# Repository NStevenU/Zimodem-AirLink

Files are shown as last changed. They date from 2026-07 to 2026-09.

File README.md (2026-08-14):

<p align="center">
  AirLink Serial 56K Logo
</p>

<p align="center">
  <strong>ESP32-C3 기반 IBM PC Serial - WiFi 모뎀 에뮬레이터 (한국어 지원!)</strong><br>
  <em>Based on <a href="https://github.com/bozimmerman/Zimodem">Zimodem 4.0</a> by Bo Zimmerman</em>
</p>

---

## 📌 Overview
**AirLink 56K**는 Zimodem 펌웨어를 기반으로 최적화와 수정, 개선을 거친 WiFi 모뎀 펌웨어입니다. 레트로 IBM PC 환경에 완벽하게 호환되도록 설계되었으며, **ESP32-C3** 칩셋의 성능을 활용하여 실제 모뎀의 감성적인 사운드와 현대적인 편의성(VT100 메뉴, 한글 지원 등)을 동시에 제공합니다.
(AirLink는 실제로 존재하는 브랜드가 아니며 그냥 어울리도록 만든 것입니다. 누구나 따라 사용하실 수 있습니다.)

> 🇰🇷 **Note for International Users:** 
> This firmware is highly optimized for the Korean environment. While English is fully supported, please note that Korean is set as the default language.

**중요한 점**으로 이 펌웨어는 단순히 개인적인 용도로 프로젝트를 만들어 만든 것이기 때문에 최종 완성본이 아니며, 각종 문제 또는 미숙한 부분, 버그등이 발생할 수 있습니다.
또한 수정되거나 추가된 기능 대비 설명이 부족한 부분도 있습니다.

## ✨ Key Modifications & Features
* **최신 개발 환경 대응**: 최신 Arduino IDE, ESP-IDF v5.0 이상 대응
* **AirLink 브랜드 적용**: ESP32-C3, MAX3232, Buzzer를 결합한 하드웨어에 사용할 브랜드 적용(그래야지 진짜 물건같고 있어보이잖아요?ㅎㅎ)
* **IBM PC 전용 최적화**: 범용 레트로 PC 지원 코드를 덜어내고, ESP32-C3에 맞지 않는 불필요한 명령어 비활성화
* **모뎀 사운드 에뮬레이션!!!**: 
  * 전화 벨소리(Ringing), DTMF 다이얼 톤, V.90 모뎀 접속음을 추가 및 유기적 연동
  * 실제 문자열 접속 주소 입력 시, 사운드 출력을 위해 DTMF 음으로 자동 대체하여 레트로 감성 극대화
* **VT100 대화형 설정 메뉴**: 터미널에서 직관적으로 모뎀을 세팅할 수 있는 `AT+CONFIG` 메뉴 전면 개편
* **완벽한 한국어(EUC-KR) 지원**: 설정 메뉴 및 출력 메시지에서 영어/한국어 선택 기능 추가
* **사용자 편의성 강화**: 자체 도움말 기능(`AT+HELP`) 및 기타 마이너 편의 기능 탑재
* **한국 맞춤 최적화**: 인터넷 연결 기능인 SLIP, PPP기능의 가상번호를 PC통신 느낌이 나도록 014XY로 바꾸어, 01480, 01481로 수정
* **완벽한 Windows 9X PPP 호환성**: 
  * 기존 펌웨어에 없던 PAP(Password Authentication Protocol) 인증 로직을 자체적으로 완전 신규 구현하여 "사용자 이름 및 암호 확인 중" 화면에서 멈추는 고질적 문제 해결
  * IPCP(IP Control Protocol) 교섭 과정에서 모뎀과 윈도우 간의 IP 할당 충돌(Conflict) 방지 알고리즘 적용 및 NAK/REJ 핸들링 추가
* **레트로 모뎀 속도 완벽 에뮬레이션 (QoS 대역폭 제한)**:
  * Token Bucket 알고리즘을 도입하여 56K, 33.6K, 28.8K, 14.4K, 9.6K, 2.4K 등 과거 전화선 모뎀 특유의 병목 현상과 느린 전송 속도를 완벽하게 재현 (PPP, SLIP, 일반 Stream 모드 전체에 일괄 적용, 물론 무제한(0)으로 설정하여 최고속도로 사용가능)
* **상태 표시(Status) LED 기능 활성화**:
  * ESP32-C3 하드웨어 핀 맵핑을 전면 재정비하고, 직관적인 상태 파악을 위한 3개의 LED(PWR 전원, WIFI 연결 상태, RX/TX 데이터 송수신) 깜빡임 기능 추가
* **USB 비상 디버그 콘솔 (Emergency Backdoor)**:
  * 본선 시리얼 터미널이 먹통이 되었을 때 칩의 USB 포트(115200bps)로 직접 연결하여 하드웨어 강제 재부팅(`RESET`), 속도 강제 복구(`BAUD=`), 공장 초기화(`FACTORY`) 등을 수행할 수 있는 비상 커맨드 시스템 구축

## 🔌 Hardware Configuration (AirLink ESP32-C3 Pinout)

기존 범용 ESP32에 맞춰져 있던 핀 배열을 AirLink 하드웨어(ESP32-C3)에 최적화하여 새롭게 맵핑했습니다.<br/>모뎀 터미널 프로그램 설정 시 아래의 기본값을 참고하세요.

### 1. 시리얼 통신 기본 설정 (Default Serial Settings)
* **기본 모뎀 통신 포트 (UART0)**
  * **기본 속도 (Baud Rate)**: `115200 bps` 
  * **통신 포맷**: `8-N-1` (8 Data bits, No Parity, 1 Stop bit)
  * **흐름 제어 (Flow Control)**: `소프트웨어 방식 (XON/XOFF)`이 기본으로 활성화되어 있으며, 필요시 `AT&K` 명령어, 또는 `AT+CONFIG` 메뉴에서 하드웨어(RTS/CTS) 제어로 변경할 수 있습니다. **추천하는 것은 이후 아래에 설명된 `하드웨어 방식 (CTS/RTS)`을 사용하는 것입니다.**
* **USB 비상 디버그 포트 (USB CDC)**
  * 기기를 컴퓨터에 직접 USB로 연결하면 **비상 콘솔(115200 bps)** 에 접속할 수 있습니다. 메인 통신이 설정 오류로 먹통이 될 경우, 이 포트를 통해 `BAUD=`, `FACTORY`, `RESET` 등의 복구 명령을 내릴 수 있습니다.

### 2. ESP32-C3 핀 맵핑 (Pin Map)
사용자 커스텀 보드를 제작하거나 모듈을 직접 배선할 경우 아래의 핀 배열을 준수해야 합니다.

| 기능 (Function) | 설명 (Description) | GPIO 번호 (ESP32-C3) |
|:---:|---|:---:|
| **TXD** | UART Transmit Data (PC 수신) | `기본 UART0 TX (GPIO 21)` |
| **RXD** | UART Receive Data (PC 송신) | `기본 UART0 RX (GPIO 20)` |
| **DCD** | Data Carrier Detect | `GPIO 8` |
| **DTR** | Data Terminal Ready | `GPIO 5` |
| **DSR** | Data Set Ready | `GPIO 4` |
| **RTS** | Request To Send | `GPIO 2` |
| **CTS** | Clear To Send | `GPIO 3` |
| **RI** | Ring Indicator | `GPIO 1` |
| **SND** | 오디오 출력 (Buzzer/Speaker) | `GPIO 6` |
| **WIFI LED** | WiFi 연결 상태 표시 (Active LOW) | `GPIO 10` |
| **RXTX LED** | 데이터 송수신 표시 (Active LOW) | `GPIO 9` |
| **PWR LED** | 전원 표시 | 하드웨어 직결 권장 |
| **AA/OTH** | Auto Answer / Pulse Dial 핀 | `GPIO 0` / `GPIO 7` |

### 3. 아두이노 펌웨어 업로드 가이드 (Arduino Firmware Upload)
AirLink 펌웨어를 ESP32-C3 모듈에 빌드 및 업로드하기 위한 Arduino IDE 설정 방법입니다.

1. **사전 준비 사항**
   * **Arduino IDE**: `v2.3.10` 설치
   * **esp32 보드 패키지**: `v3.3.10` 설치 (`툴 -> 보드 -> 보드 매니저`에서 `esp32` 검색 후 `3.3.10` 버전 선택 및 설치)
2. **프로젝트 열기**
   * 펌웨어 소스코드 전체를 다운로드한 후, `zimodem/zimodem.ino` 파일을 열어줍니다.
3. **Arduino IDE 보드 설정 (`툴` 메뉴)**
   * **보드 (Board)**: `ESP32C3 Dev Module`
   * **USB CDC On Boot**: `Enabled`
   * **CPU Frequency**: `160MHz (WiFi)`
   * **Erase All Flash Before Sketch Upload**: `Enabled` *(※ 단, 최초 업로드 이후 단순 업데이트 시에는 `Disabled`)*
   * **Partition Scheme**: `Default 4MB with spiffs (1.2MB APP/1.5MB SPIFFS)` *(※ 펌웨어 및 SPIFFS 파티션을 위해 반드시 **4MB Flash 버전**의 ESP32-C3 모듈을 사용해야 합니다)*

### 4. 하드웨어 자재 및 제작 레퍼런스 (Hardware Build & Reference)
자체 제작 시 사용된 주요 자재와 만능기판 배선, 조립 및 완제품 사진 레퍼런스입니다.<br/>
3D 프린팅 케이스는 3d case폴더 내에 stl파일로 존재하니 다운받아 출력하시면 됩니다.

#### 📦 주요 사용 자재
* **MCU**: ESP32-C3 Super Mini (4MB Flash 버전 필수)
* **시리얼 변환기**: MAX3232 (RS232 to TTL) **아래에 설명된 `하드웨어 방식 (CTS/RTS)`을 사용하기 위한 핀을 추가하는 작업을 추천드립니다.**
* **오디오**: 수동 부저 (Buzzer)
* **상태 표시등**: 5파이 LED 3개 (PWR, RX/TX, WIFI)
* **저항**: SMD 1206사이즈 560옴 저항 3개
* **나사**: M2 x 6 둥근머리 태핑나사 3개 

#### 📐 회로 설계 & 만능기판 배선
만능기판을 활용한 핀 배선 및 설계 레이아웃 예시입니다.<br/>
이 설계는 `소프트웨어 방식 (XON/XOFF)`기준이며, `하드웨어 방식 (CTS/RTS)`을 사용하실려면 배선 추가가 필요합니다.<br/>
노트북이나 컴퓨터 등에 바로 직결로 연결하실 예정이거나, 또는 작동이 되지않으면 MAX3232쪽 핀헤더에서 RXD와 TXD를 서로 바꿔서 연결하여야합니다.<br/>
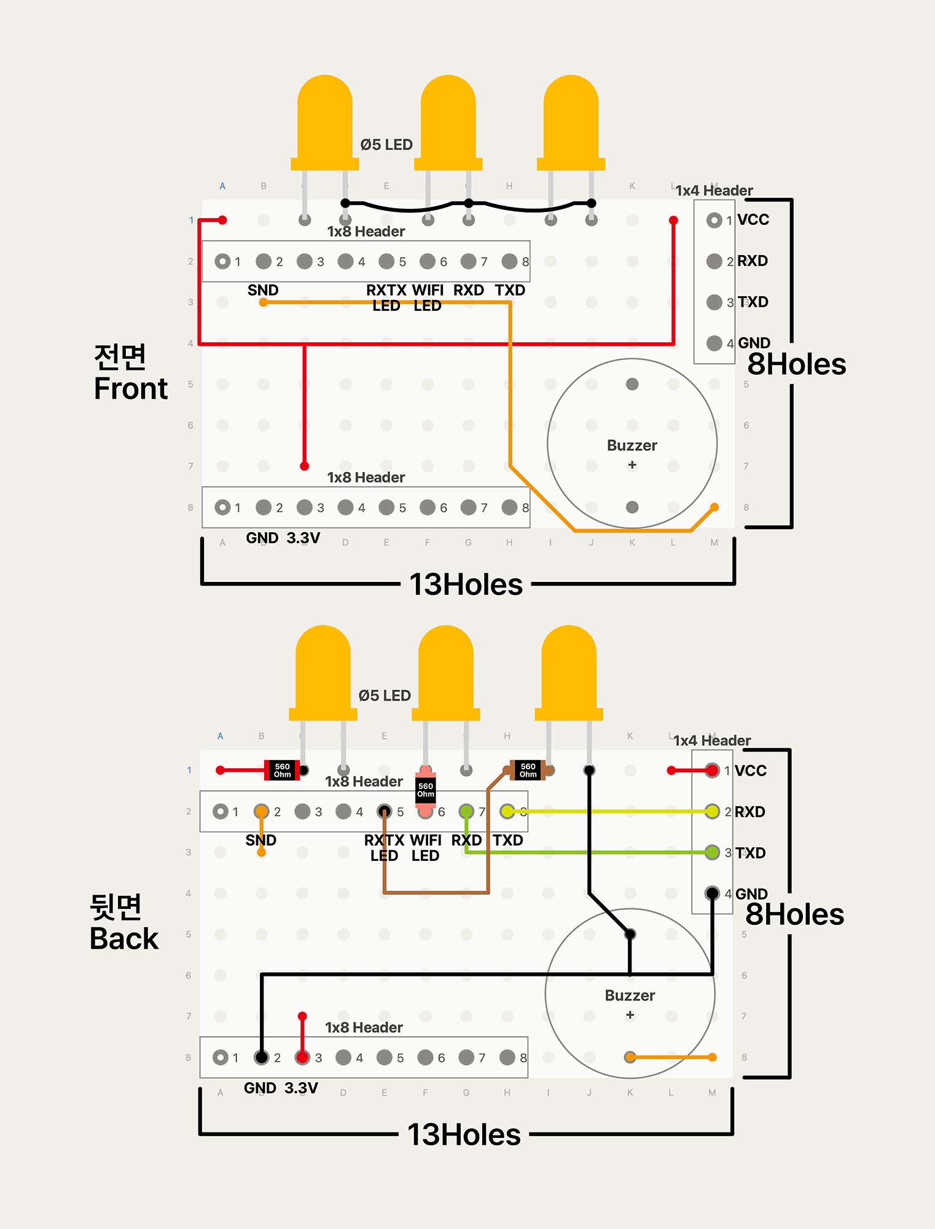
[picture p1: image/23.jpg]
회로 설계


#### 🔌 실제 만능기판 실장
실제 만능기판 부품 배치 및 납땜 실장 모습입니다.<br/>
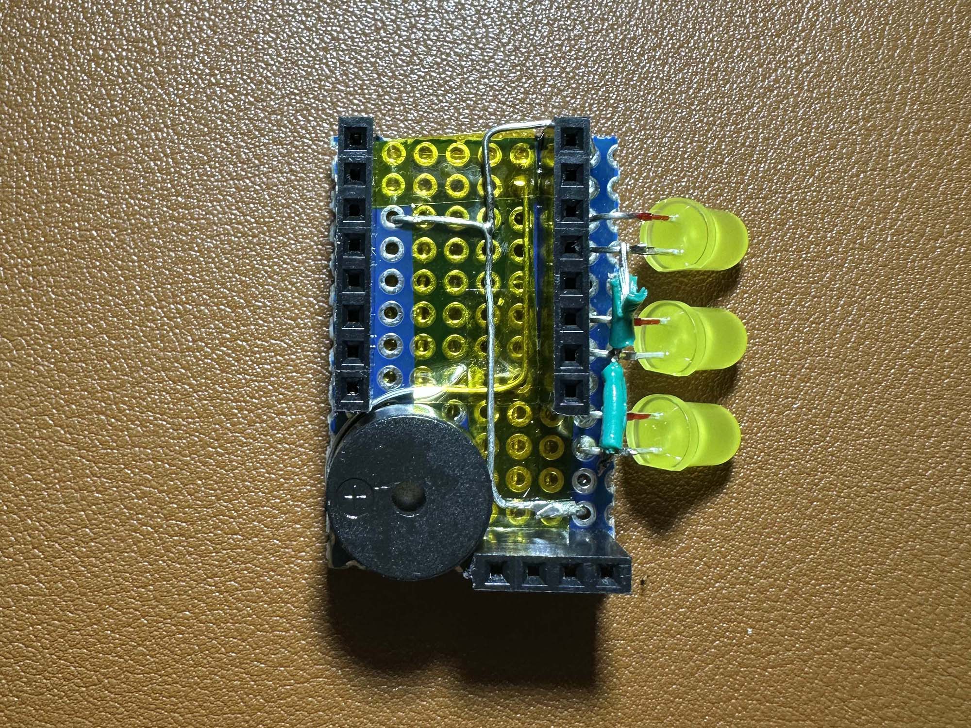
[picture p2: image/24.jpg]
만능기판 실장 1
<br/>
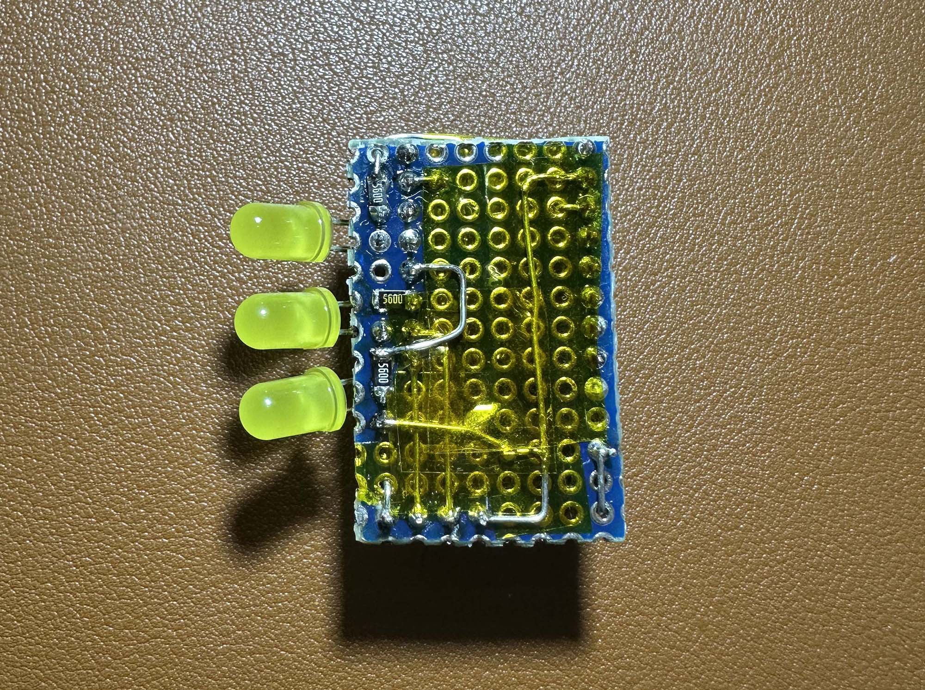
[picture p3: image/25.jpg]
만능기판 실장 2


#### 📦 케이스 및 내부 조립
케이스 외관 및 내부 조립 배치 사진입니다.<br/>
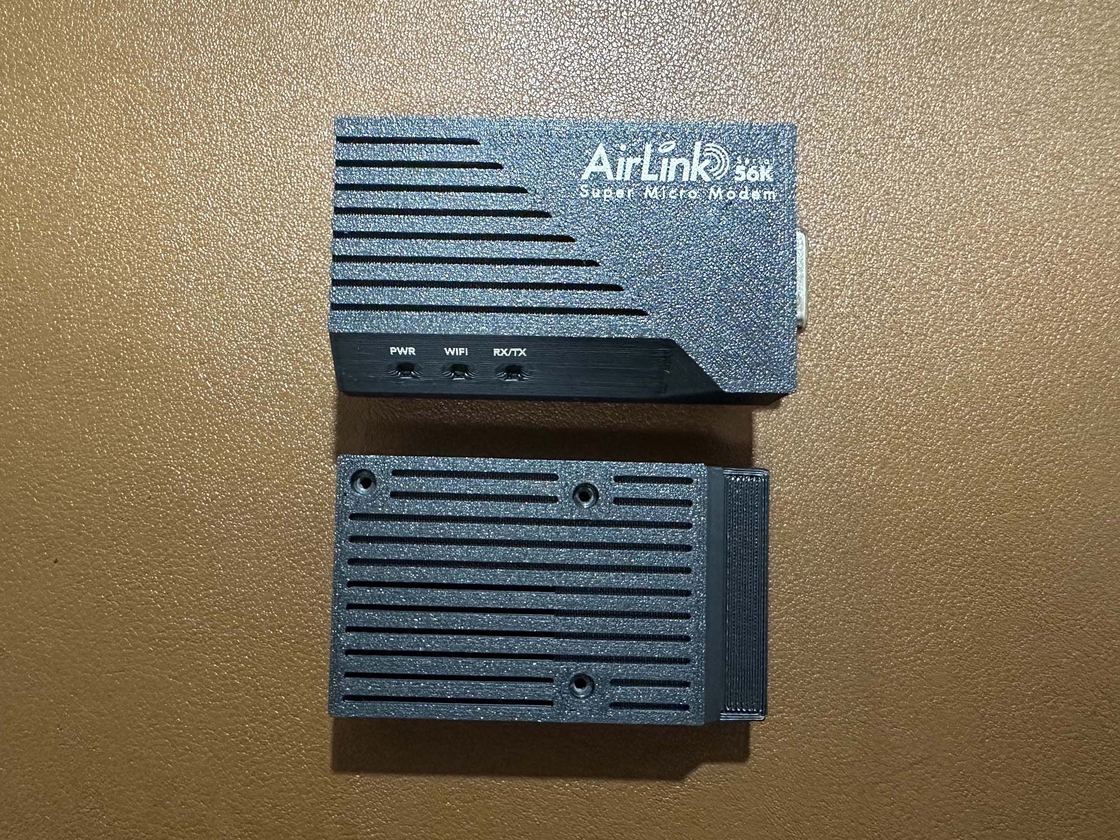
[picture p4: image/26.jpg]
케이스 사진
<br/>
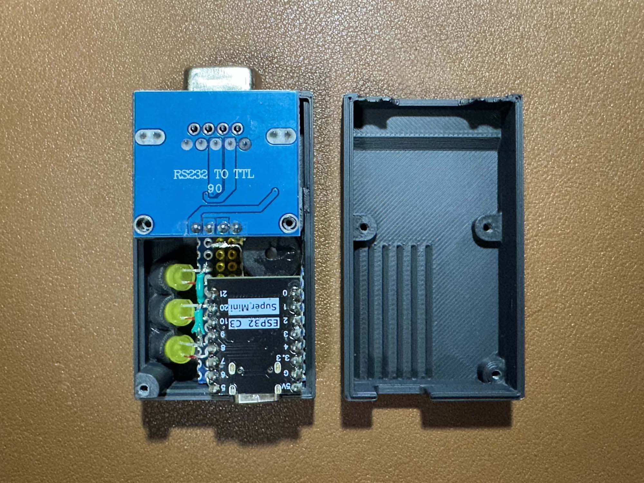
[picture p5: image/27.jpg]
조립 내부 사진


#### 🎨 전체 디자인 및 외관
완성된 AirLink 56K 모뎀의 디자인 모습입니다.<br/>
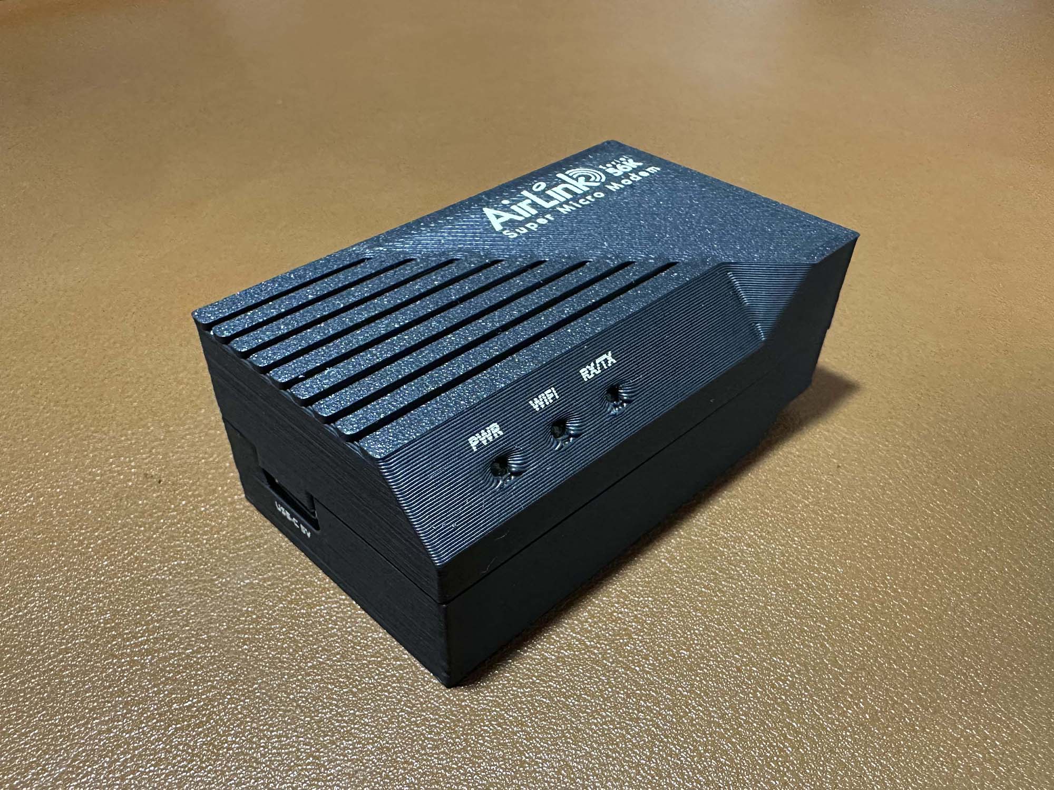
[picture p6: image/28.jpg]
전체 디자인 1
<br/>
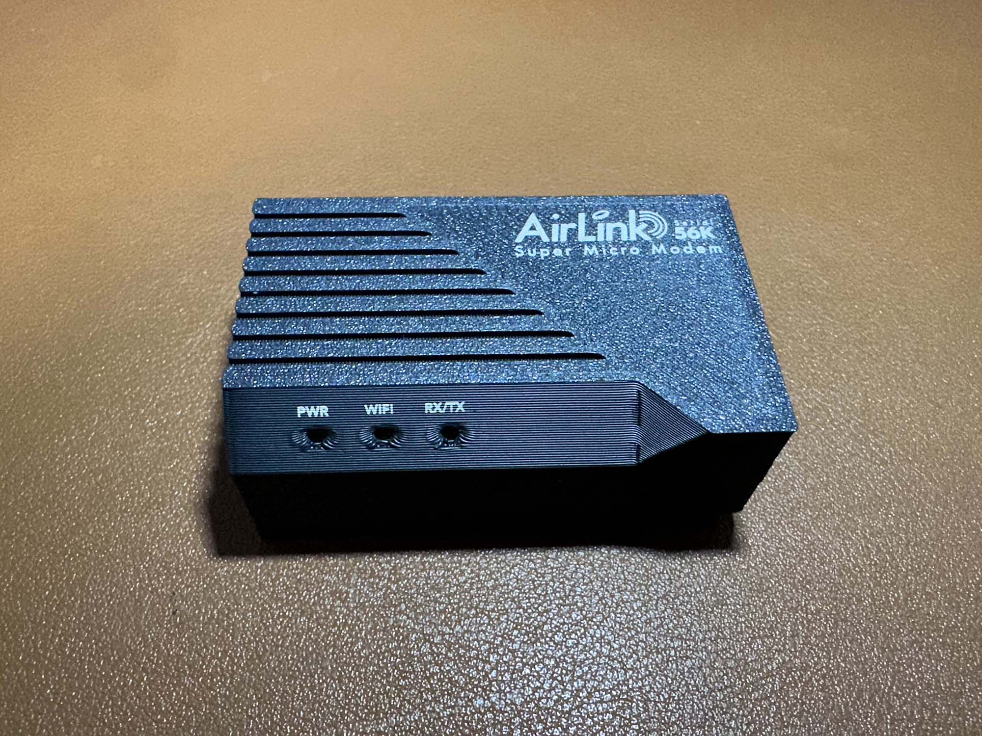
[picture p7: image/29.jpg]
전체 디자인 2
<br/>
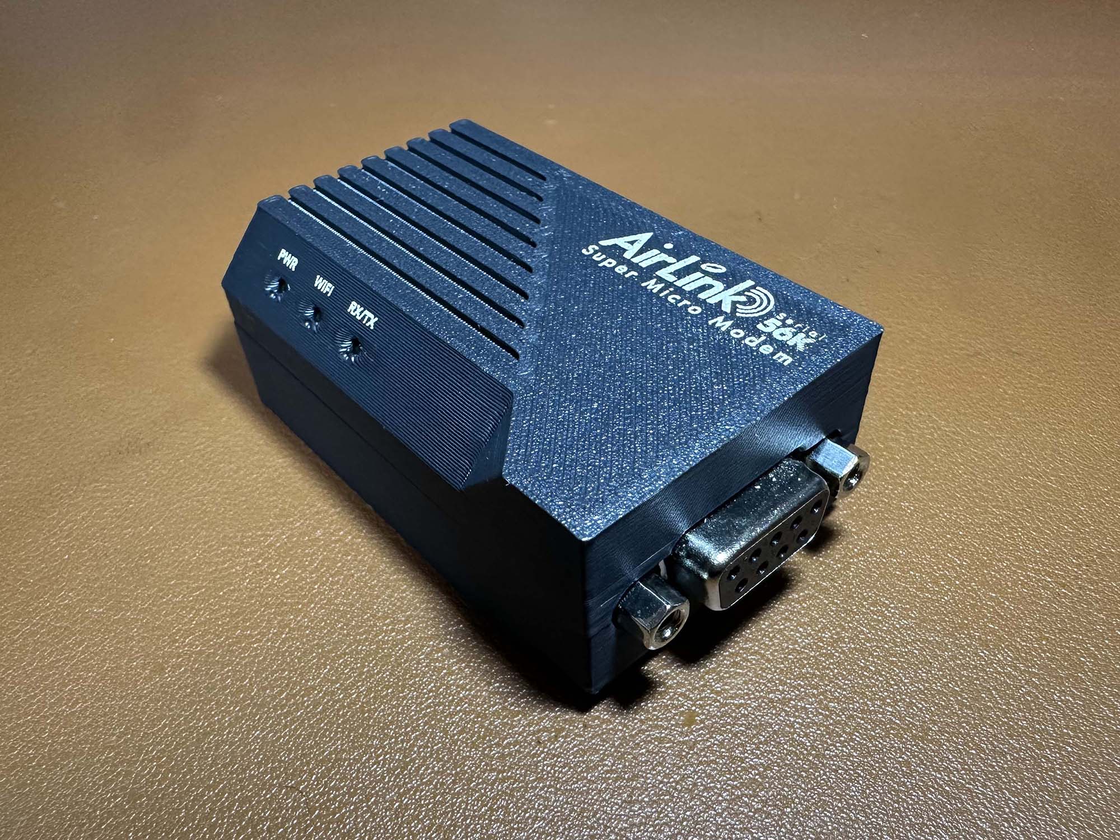
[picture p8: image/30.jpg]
전체 디자인 3
<br/>
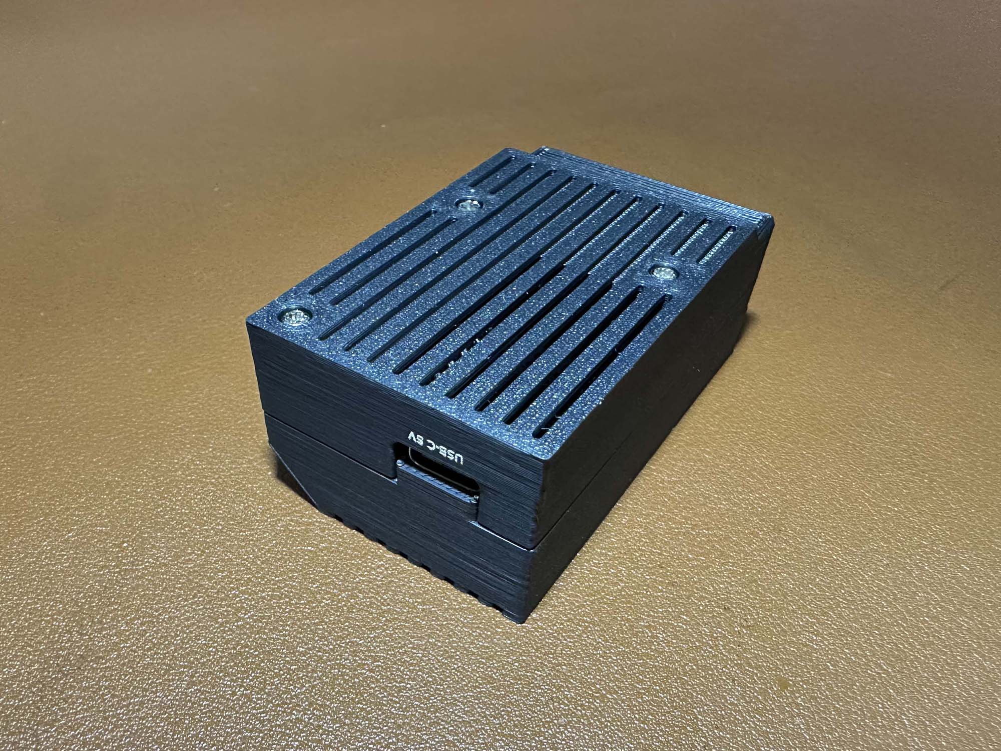
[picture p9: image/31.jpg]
전체 디자인 4
<br/>
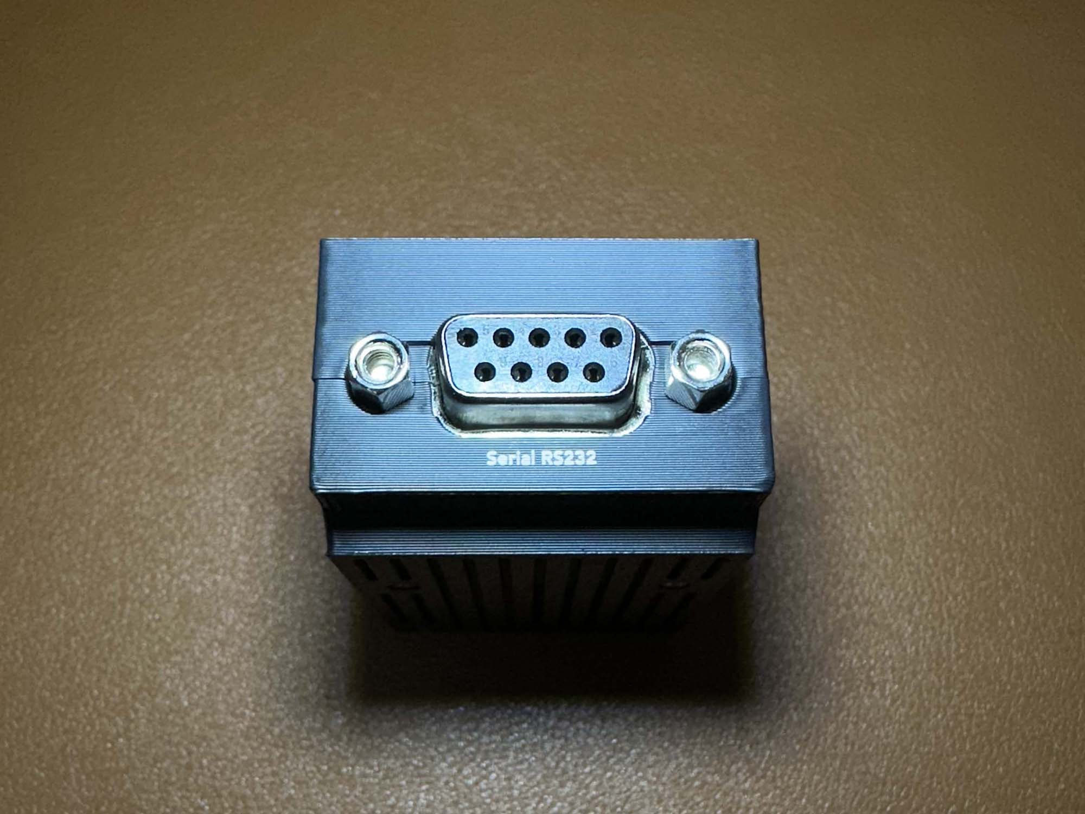
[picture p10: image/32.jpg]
전체 디자인 5


#### 💡 작동 및 LED 동작
전원 및 데이터 송수신(RXTX), WiFi 상태 LED 동작 모습입니다.<br/>
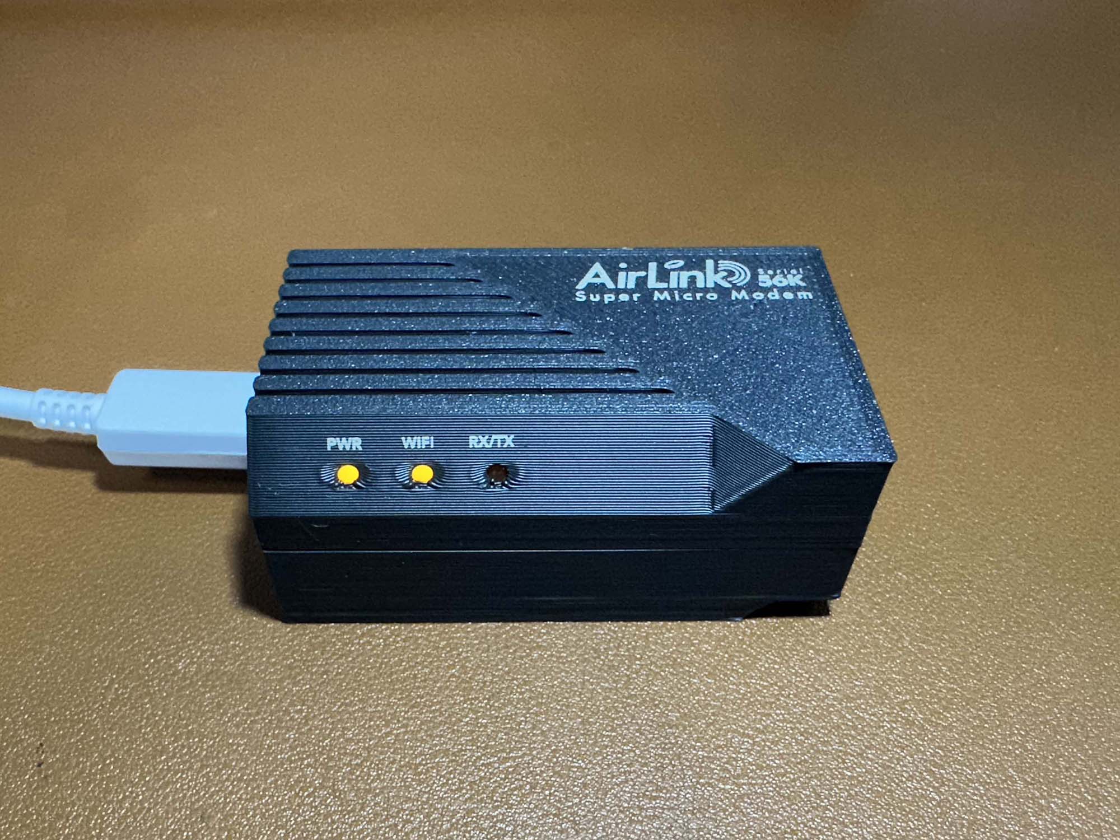
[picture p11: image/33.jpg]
작동 및 LED 동작


#### 📐 하드웨어 방식 (CTS/RTS)핀을 추가하기 위한 MAX3232 수정
알리익스프레스나 타오바오, 국내등에서 저렴하게 구할 수 있는 4핀방식 MAX3232는 사실 CTS/RTS핀 추가가 가능합니다.<br/>
연결만 되어있지 않을 뿐이라, 사진같이 배선을 해주면 CTS/RTS핀을 뺄 수 있습니다.<br/>
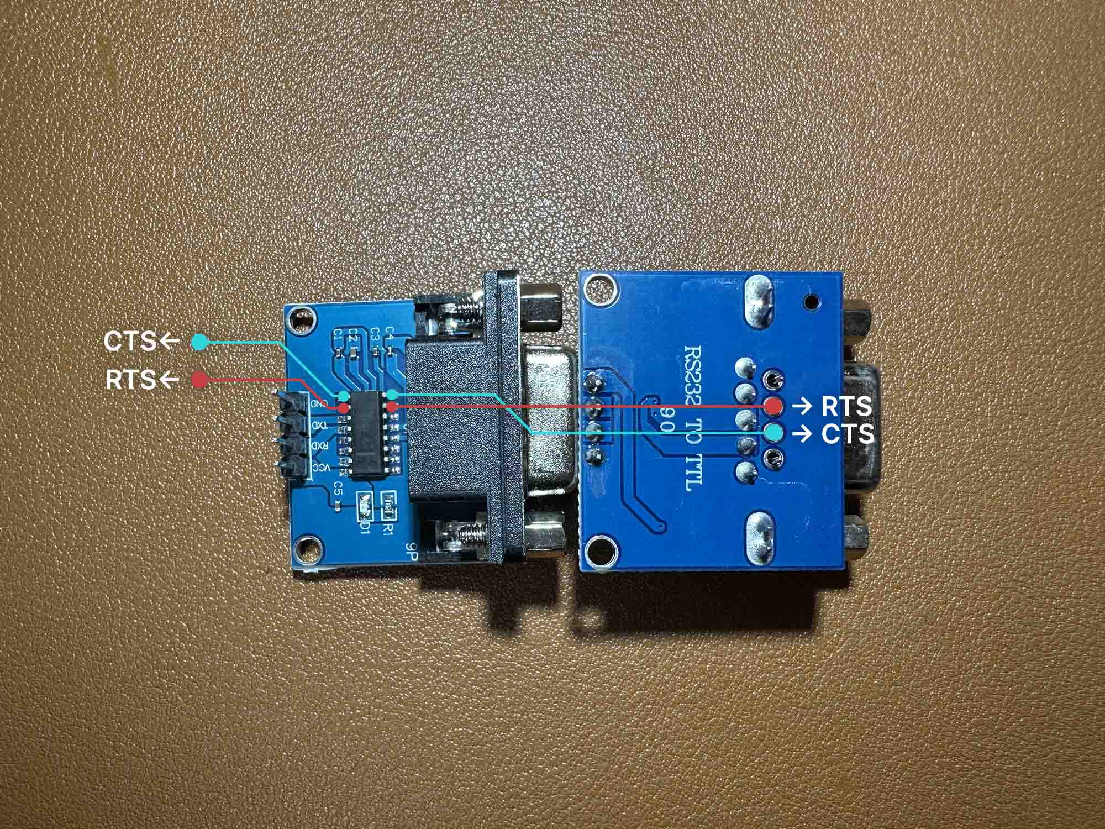
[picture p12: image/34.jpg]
<br/>
저의 경우는 사진과 같이 땜빵하여 직결로 연결하였습니다.<br/>
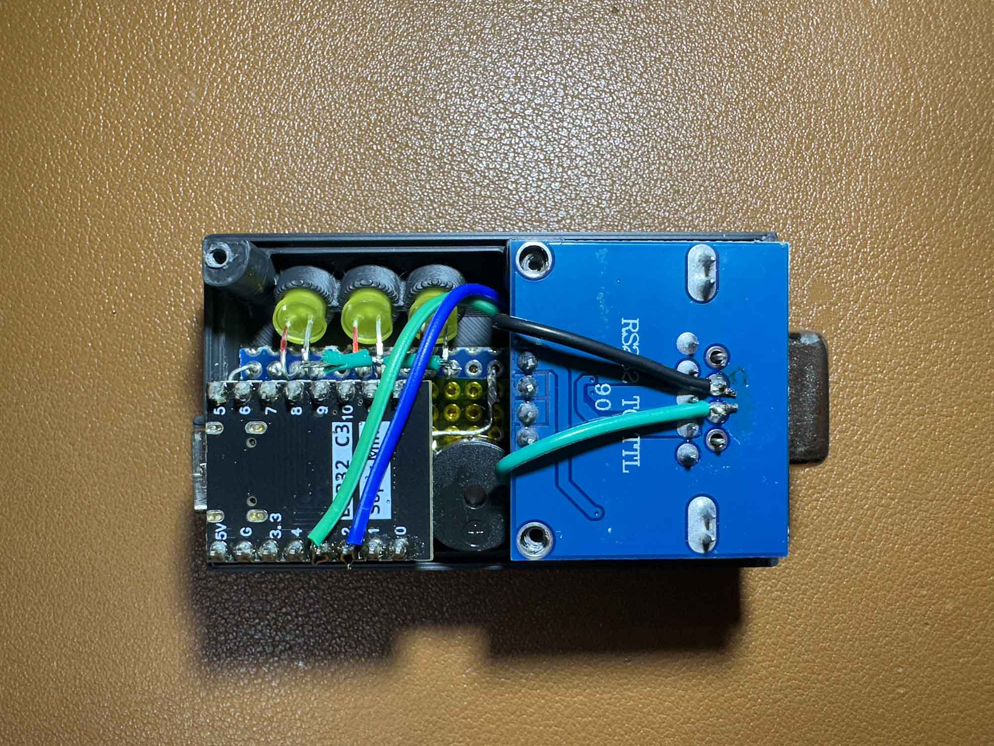
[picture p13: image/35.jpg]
<br/>
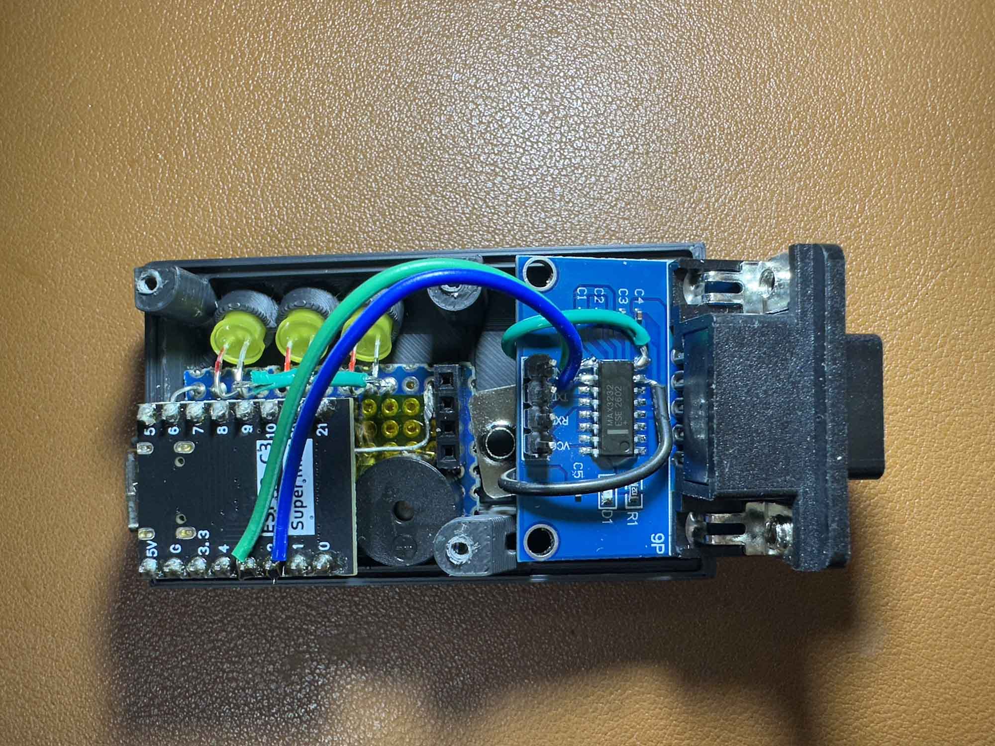
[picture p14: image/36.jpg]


## 📖 사용 방법 (How to Use)
**※ 본 가이드는 Windows 9X (사진은 Windows 95) 환경을 기준으로 작성되었습니다.**

### 1. 하드웨어 연결 및 포트 기본 설정
모뎀을 사용하기 전, 올바른 순서로 연결하고 통신 포트를 설정해야 합니다.

1. **하드웨어 연결**: 먼저 AirLink 보드의 **USB-C 포트에 전원을 연결**한 후, **그 뒤에 PC와 시리얼 케이블을 연결**합니다.
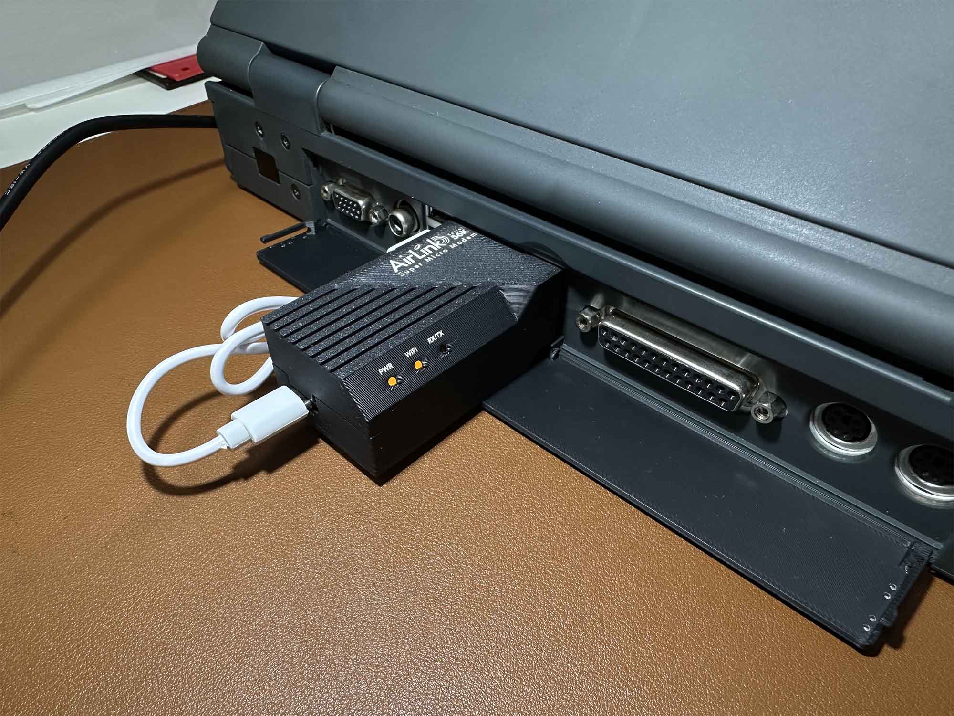
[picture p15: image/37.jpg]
하드웨어 연결
<br/>

### 2. Windows 9X 모뎀 등록 방법
이제 설정한 통신 포트에 표준 모뎀을 등록해야 합니다.

1. **제어판 -> 모뎀**을 실행하고 **`다음`** 을 누릅니다.<br/>
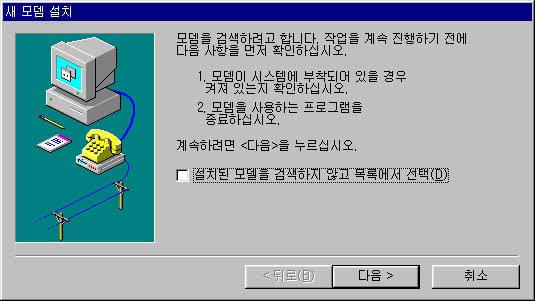
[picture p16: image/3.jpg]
모뎀을 검색할려고 합니다
   
2. 자동으로 모뎀을 검색하게 두었다가, 만약 "모뎀을 찾을 수 없습니다"라고 나오면 **`다음`** 을 누릅니다.<br/>
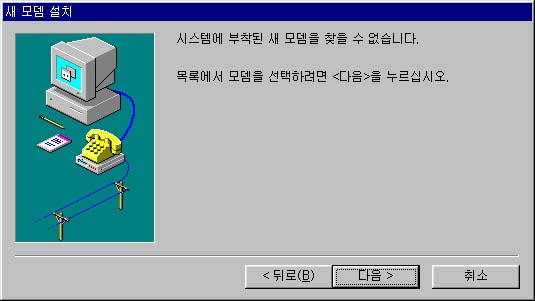
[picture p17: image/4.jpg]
모뎀을 찾을 수 없습니다
   
3. 제조업체 목록에서 **`표준 모뎀 형식`** 을 고르고, 모델에서 **`표준 28800 bps 모뎀`** (목록에 보이는 것 중 제일 높은 속도)을 선택합니다.<br/>
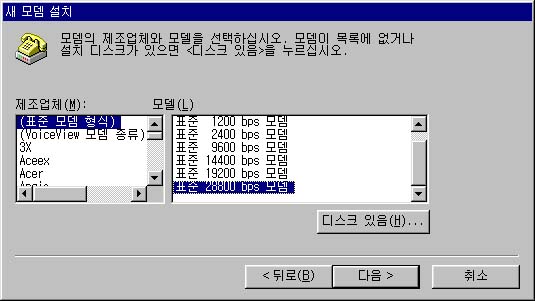
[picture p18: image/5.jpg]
모뎀의 제조업체와 모델을 선택하십시오
   
4. 시리얼 케이블이 연결된 **포트를 선택**하고 **`다음`** 을 눌러 완료합니다.<br/>
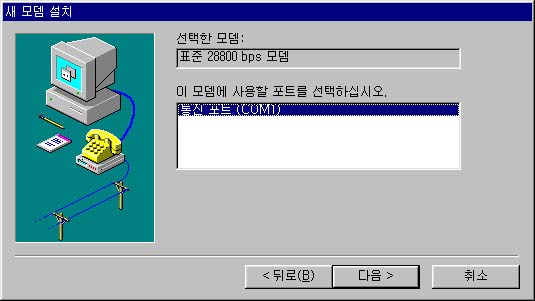
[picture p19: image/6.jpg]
이 모뎀에 사용할 포트를 선택하십시오
   
   <br/>
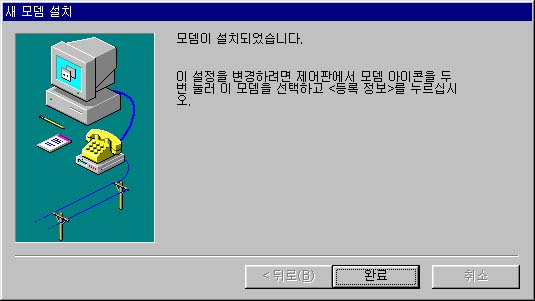
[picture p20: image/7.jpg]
모뎀이 설치되었습니다
   
6. 모뎀 목록 창으로 돌아와서, 방금 등록된 모뎀을 선택하고 **`등록 정보`** 를 누릅니다.<br/>
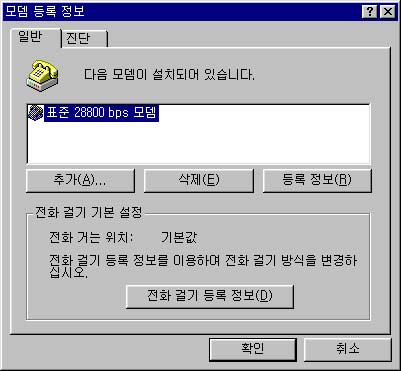
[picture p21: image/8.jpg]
모뎀 등록 정보
   
7. 일반 탭에서 **최대 속도를 `115200`** 으로 변경합니다.<br/>
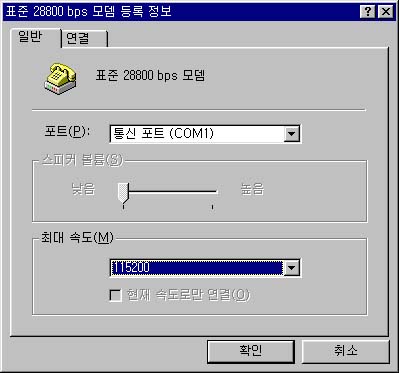
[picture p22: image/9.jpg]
최대 속도
   
8. **`연결`** 탭으로 이동하여 **`고급`** 버튼을 누릅니다.<br/>
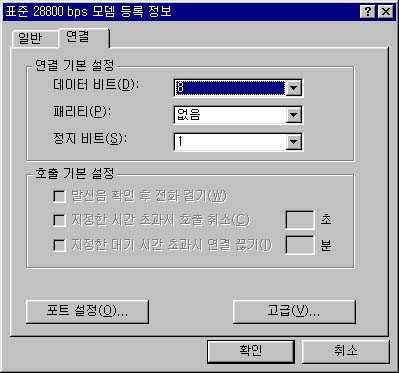
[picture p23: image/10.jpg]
고굽
   
9. 고급 연결 설정에서 **흐름 제어 사용**이 체크되어있는지 확인 후 **`소프트웨어 (XON/XOFF)`** 로 선택한 뒤 확인을 누릅니다.<br/>
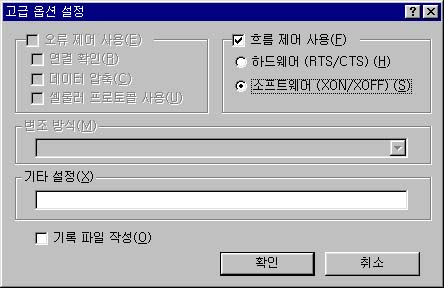
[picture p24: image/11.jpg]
고급 옵션 설정
   

### 3. 초기 부팅 후 WiFi 설정
1. 모뎀이 준비되었다면, 터미널 프로그램(예: 새롬데이타맨, 이야기 등)을 엽니다.<br/>
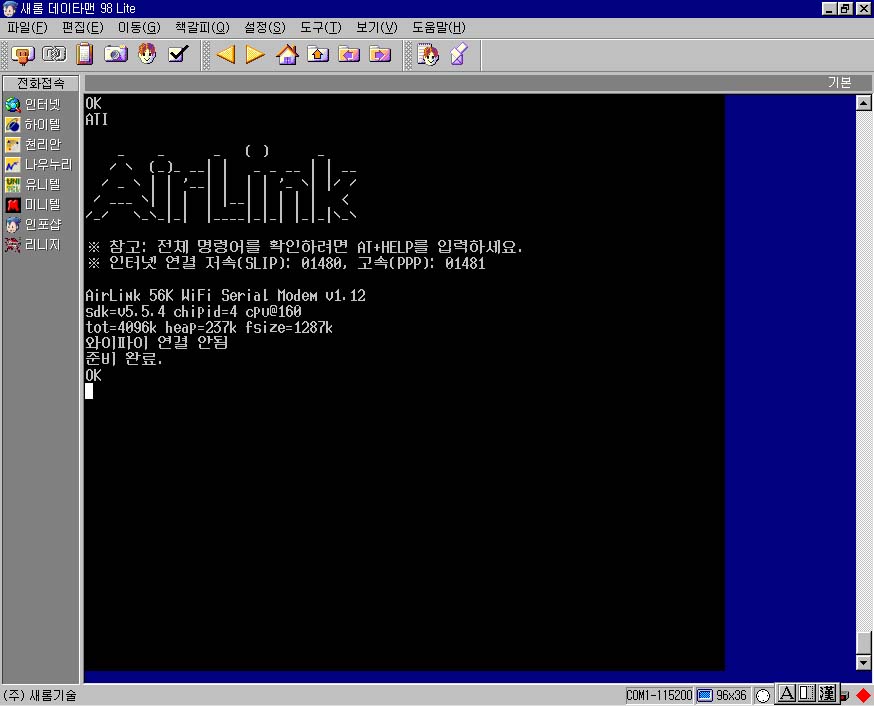
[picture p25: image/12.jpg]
새롬 데이타맨 98
   
1. 터미널에서 `AT+CONFIG`를 입력하여 대화형 설정 메뉴로 진입합니다.
2. 메뉴에서 `w`를 입력하여 WiFi 설정으로 들어갑니다.<br/>
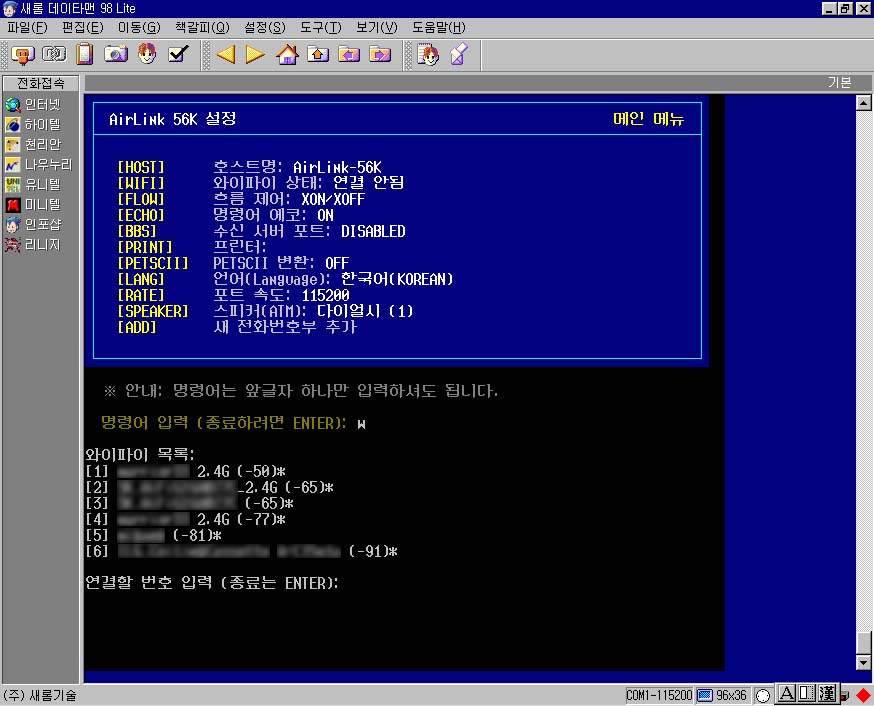
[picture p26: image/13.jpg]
   
3. SSID 네트워크 목록 번호를 입력하고, 공유기 비밀번호를 입력합니다.
4. DHCP 설정 화면이 나타나면, `d`를 입력하여 **DHCP 사용**으로 전환(Toggle)한 뒤 엔터를 누릅니다.<br/>
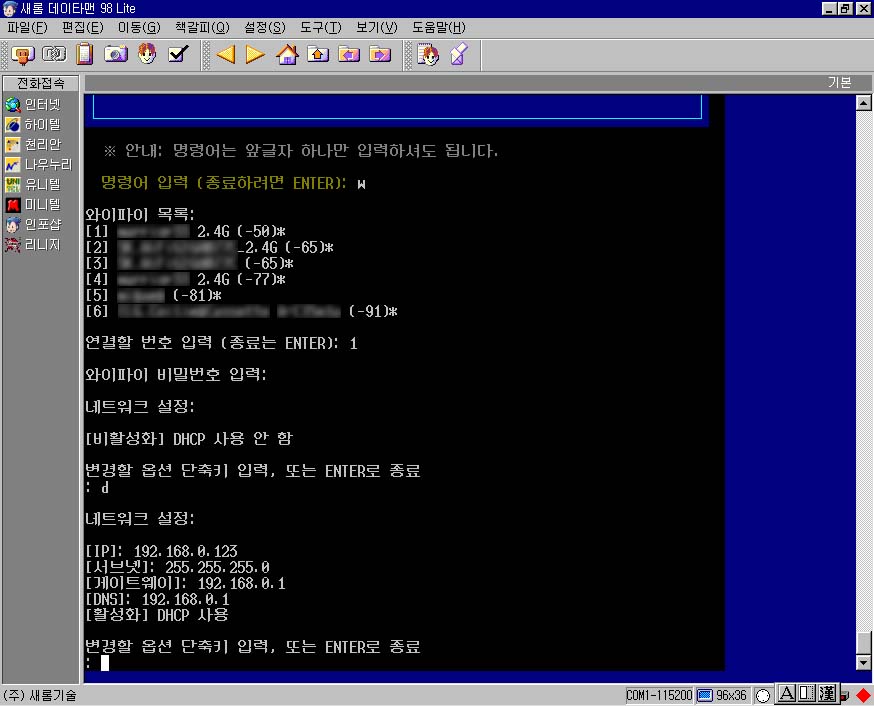
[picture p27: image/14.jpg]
WIFI 설정
   
5. 연결 성공시 `와이파이 상태:`에 SSID가 표시됩니다. `엔터`를 눌러 저장하고, `y`를 눌러 저장합니다.<br/>
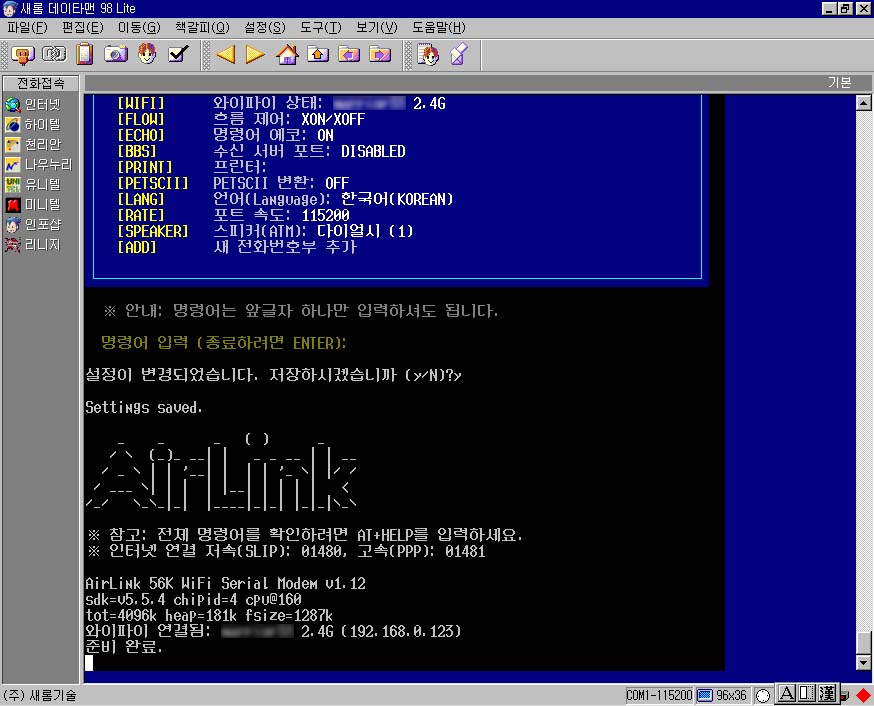
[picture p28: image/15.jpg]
최종 설정
   
6. 만약 `하드웨어 방식 (CTS/RTS)`으로 작업하셨다면 위 설정에서 `흐름 제어`를 `하드웨어 (CTS/RTS)` 로 선택한 뒤 확인을 누릅니다.<br/>
이후 터미널 프로그램과 연결을 끊고, 위 2번에서 진행한 `모뎀 등록 정보` 내에서 `하드웨어 (CTS/RTS)`로 바꿉니다.<br/><br/>

이제 모든 준비가 끝났습니다!

### 4. BBS 접속하기
아주 쉽습니다. `ATDT"원하는 주소"`를 입력하면 됩니다.<br/>
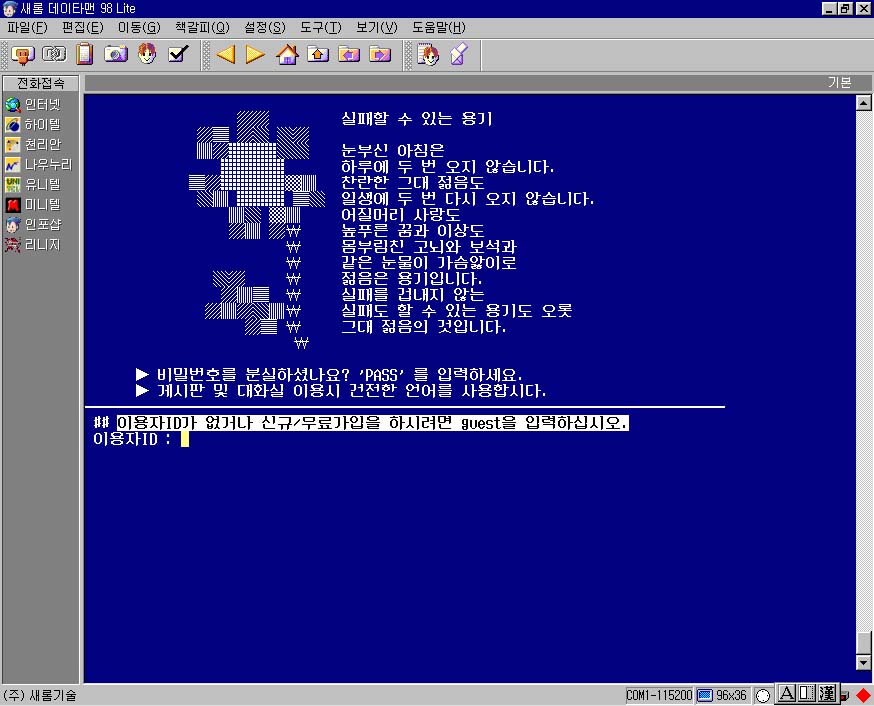
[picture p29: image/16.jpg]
BBS접속


### 5. PPP 인터넷 접속하기 (01481)
다이얼업 네트워킹을 통해 TCP/IP 웹서핑에 접속합니다.

#### [전화 접속 네트워킹 설정]
1. **새 연결 만들기**: `전화 접속 네트워킹`에서 새로 연결을 엽니다.
2. 사용할 모뎀을 앞서 만든 `표준 28800 bps 모뎀`으로 선택하고, 전화번호에 **`01481`** 을 입력합니다.
3. 생성된 아이콘을 우클릭하여 `속성`에 들어갑니다. 국가/지역 번호 사용을 **해제**합니다.<br/>
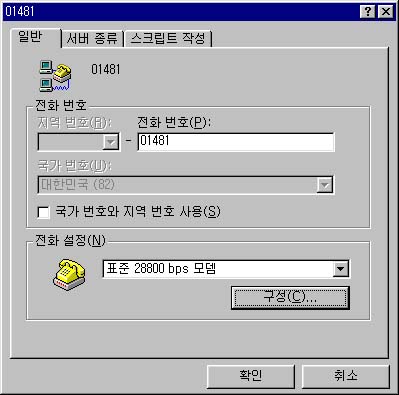
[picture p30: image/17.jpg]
01481 일반
   
4. `서버 종류` 탭으로 들어갑니다.
5. **`네트워크에 로그온`, `소프트웨어 압축 가능`, `암호화`** 를 끕니다.
6. 지원되는 네트워크 프로토콜에서 **NetBEUI, IPX/SPX 호환 체크 해제**, 오직 **TCP/IP**만 체크합니다.<br/>
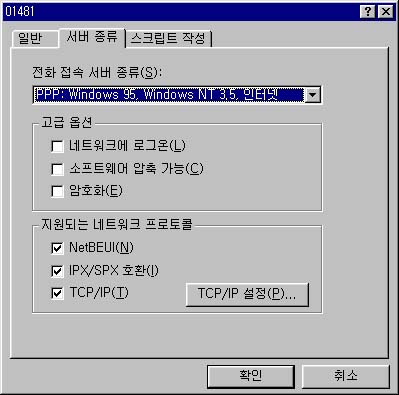
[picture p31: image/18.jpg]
01481 서버 종류
   

#### [인터넷 접속!]
1. 연결 아이콘을 더블클릭합니다.
2. 접속 창이 뜨면 사용자 이름에 **`airlink`**, 암호에 **`1111`** 을 입력합니다.<br/>
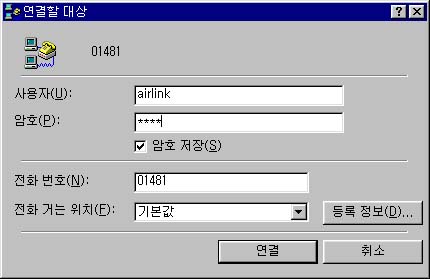
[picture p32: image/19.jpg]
연결할 대상
   
3. `연결` 버튼을 누르면 인터넷이 연결됩니다.<br/>
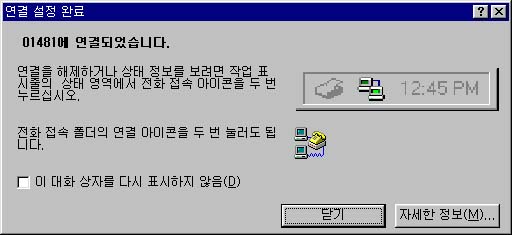
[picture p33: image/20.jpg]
연결 설정 완료
   
   <br/>
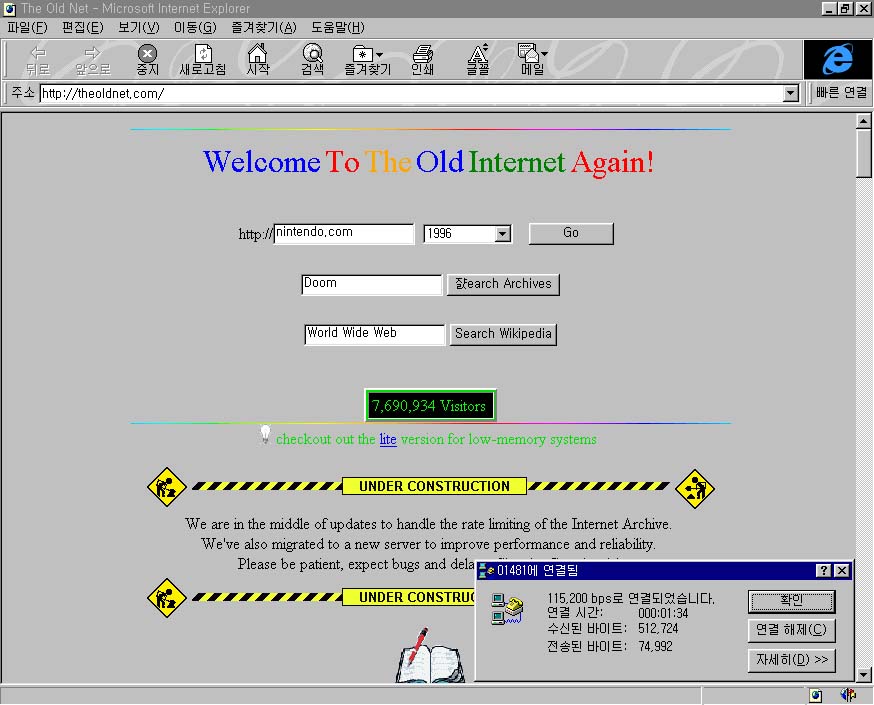
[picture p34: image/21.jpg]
IE
   

### 6. 기타 설정하기
터미널에서 `AT+CONFIG`를 입력하여 대화형 설정 메뉴로 진입합니다.<br/>
여기서 바로 **`흐름 제어`**, **`언어`**, **`포트 속도`**, **`스피커`** 등을 설정 가능합니다.<br/>
예시로 모뎀 접속음이 시끄럽고, 딜레이 없이 바로 진입하고 싶으면 **`s`** 를 눌러 스피커를 음소거로 설정하면 됩니다.<br/>
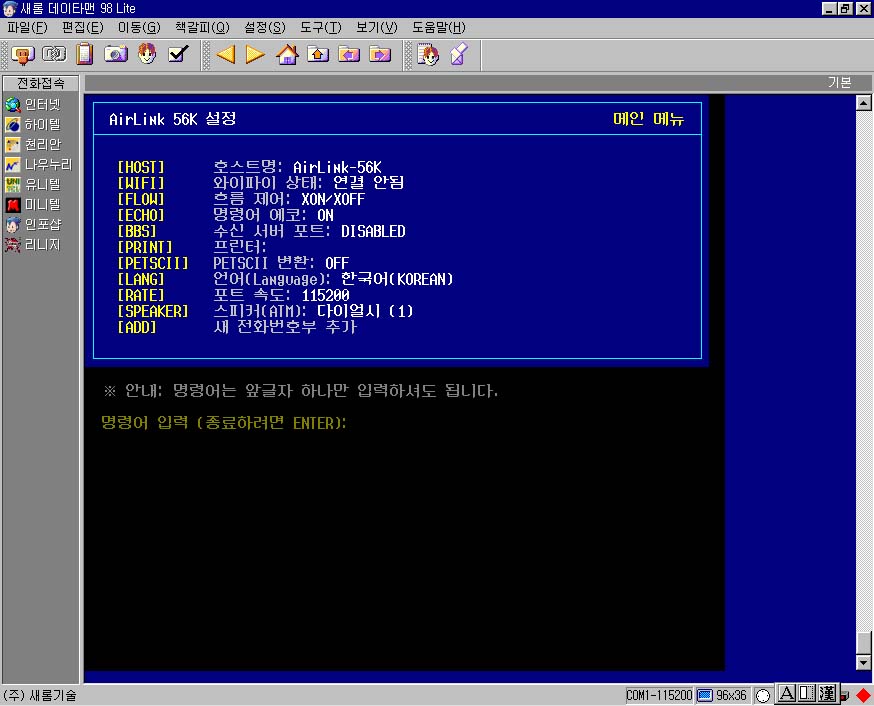
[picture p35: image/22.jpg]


## 🎵 Audio Engine Architecture

오리지널 Zimodem 펌웨어에는 사운드 출력 기능이 아예 존재하지 않았습니다. 본 프로젝트는 사운드 기능이 전무했던 기존 코드 베이스에 **소프트웨어 기반 오디오 합성 엔진(DDS)을 새롭게 구현하고 모뎀 통신 시퀀스와 완벽하게 연동**하여, 실제 56K 모뎀의 아날로그 감성을 재현해 냈습니다.

### 1. 기술적 특징 (Technical Highlights)
* **하드웨어 타이머 기반 DDS (Direct Digital Synthesis)**
  * 16kHz 주기로 동작하는 고정밀 하드웨어 타이머 ISR(인터럽트 서비스 루틴)을 사용하여 실시간으로 오디오 파형을 생성합니다.
  * 미리 계산된 256-byte 사인파 테이블(Sine Table)과 위상 누적(Phase Accumulation) 기법을 사용하여, 나눗셈 연산 오버헤드 없이 빠르고 정확한 주파수를 합성합니다.
* **비동기식 FreeRTOS 태스크 연동**
  * 사운드 재생 시 `delay()`가 발생하더라도 모뎀의 메인 통신 루프가 블로킹(멈춤)되지 않도록, 사운드 처리를 전용 FreeRTOS 태스크로 분리하여 비동기식으로 실행되도록 연동했습니다.
* **다중 주파수 믹싱 및 1-Bit PWM 출력**
  * 최대 4개의 주파수(Tone)와 1개의 화이트 노이즈를 동시에 믹싱합니다.
  * 믹싱된 디지털 값을 시그마-델타(Sigma-Delta) 방식과 유사한 비교기 로직(Mixed > 0 ? HIGH : LOW)을 거쳐 1-Bit 출력으로 변환하며, 이를 통해 수동 부저(Passive Buzzer)에서도 레트로하고 아날로그적인 질감의 소리를 냅니다.

### 2. 주요 사운드 에뮬레이션 기능
* **지능형 DTMF 다이얼링 변환**
  * 사용자가 입력한 접속 주소(URL, IP 등)에서 프로토콜과 특수기호를 필터링하고, 영문자는 실제 전화 키패드 표준 매핑(예: A,B,C -> 2)에 따라 DTMF 다이얼 톤(투-티-티-티-)으로 실시간 변환하여 재생합니다.
* **V.90 모뎀 핸드셰이크 시퀀스 재현**
  * 접속 성공 시 과거 전화선 모뎀 특유의 굉음(Handshake Sound)을 재생합니다. 
  * 선형 합동 생성기(LCG) 알고리즘을 이용한 고음질 8-bit 화이트 노이즈, 주파수 스윕(Sweep), 데이터 통신 시뮬레이션 패턴을 복합적으로 조합하여 사실감을 극대화했습니다.
* **상태 기반 사운드 피드백**
  * 통신 상태(State Machine)에 따라 유기적으로 사운드가 변화합니다. (다이얼링 중 ➡️ 링백 톤 대기 ➡️ 연결 성공 시 핸드셰이크 굉음 OR 실패 시 통화 중(Busy) 톤 재생)

## 🛠️ Detailed Changelog (원본 Zimodem 대비 주요 수정 파일)
* `zimodem_sound.h` **(신규)**: 1-Bit PWM 기반 하드웨어 타이머 오디오 합성(DDS) 엔진.
* `pet2asc.h`: ESP32-C3 하드웨어 핀 맵핑 최적화, USB CDC 디버그 시리얼 통신(`DBSerial`) 정의, EUC-KR 한글 인코딩 변환 로직 추가.
* `zimodem.ino`: 메인 루프에 FreeRTOS 기반 사운드 재생 제어 연동, RX/TX/WIFI 상태 LED 점등 제어 추가, USB 비상 백도어 터미널 훅(Hook) 탑재.
* `zcommand.h` / `zcommand.ino`: AT 명령어 파서 전면 수정 (`AT+QOS`, `AT+CONFIG` 등), 한국어 번역 텍스트 적용, 모뎀 발신 시 사운드 트리거 로직 적용.
* `zconfigmode.h` / `zconfigmode.ino`: 대화형 설정 UI(`AT+CONFIG`)를 VT100 기반으로 재설계, 단축키 UI/UX 개편, 대역폭(QoS) 및 사운드 설정 메뉴 추가.
* `zpppmode.h` / `zpppmode.ino`: Windows 95 PAP 접속 인증(Authentication) 구현, 모뎀(Server)과 클라이언트(Win95) 간의 IP 할당 프로세스 규격화 및 IPCP 충돌 방지, Token Bucket 알고리즘을 이용한 QoS 속도 제한(Throttling) 구현.
* `zslipmode.ino`: SLIP 모드 연결 시 Token Bucket 기반 QoS 속도 제한 구현.
* `zstream.ino`: 일반 ATDT 통신 모드(BBS) 시에도 Token Bucket 기반 속도 제한(QoS) 적용.

## 🛠️ Hardware Requirements
* **Microcontroller**: ESP32-C3 Super Mini (4MB Flash required)
* **Serial Communication**: MAX3232 (RS232 to TTL)
* **Audio**: Buzzer (for Sound Emulation)
* **Status LEDs**: 5mm LED 3개 (PWR, RXTX, WIFI)

## 📜 Credits & License
* **Developer**: NSteven, Republic of Korea ([GitHub](https://github.com/NStevenU/))
* **Original Firmware**: Zimodem 4.0 (C)2016-2026 Bo Zimmerman ([GitHub](https://github.com/bozimmerman/Zimodem))
* **AI Assistance**: 
  * **Claude 4.6 Sonnet (Thinking)**: 사운드 엔진(DDS) 기초 아키텍처 설계 및 주요 로직 최적화 
  * **Gemini 3.1 Pro (High)**: 코드 리뷰, Windows 9X 인증 버그 수정, 핀 배열 및 통신 최적화, 한글 인코딩 및 문서화 지원
* **License**: [Apache License 2.0](LICENSE)

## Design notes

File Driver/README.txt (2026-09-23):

==============================================================================
 AirLink 56K Modem Driver for Windows 95 / 98 / ME / 2000 / XP (32-bit)
 Nexisson Tech Co., Ltd.
 Reference Architecture: U.S. Robotics 56K Faxmodem External (USR5686E)
==============================================================================

[지원 운영체제 (Supported OS)]
- Windows 95 / 95 OSR2
- Windows 98 / 98 SE
- Windows Millennium Edition (ME)
- Windows NT 4.0 (SP6)
- Windows 2000 Professional / Server
- Windows XP Home / Professional (32-bit)
※ Windows Vista 이상의 최신 OS(비스타, 7, 8, 10, 11 및 64비트)는 지원 대상에서 제외됩니다.

[드라이버 파일 설명 (Driver File)]
- AIRLINK.INF (단일 통합 드라이버) :
  • 모델명: "AirLink 56K Serial Modem"
  • 기본 흐름 제어: 하드웨어 RTS/CTS (AT&K3) 자동 기본 적용
  • 소프트웨어 흐름 제어(XON/XOFF) 전환:
    3선식 시리얼 케이블(TX/RX/GND만 연결된 환경) 사용 시,
    [제어판] -> [모뎀] -> [등록 정보] -> [연결] 탭 -> [고급] 대화상자에서
    흐름 제어를 '소프트웨어(XON/XOFF)'로 선택하면 Windows가 자동으로 AT&K4를 전송합니다.

[아키텍처 및 정석 정책 안내]
1. 통신 속도 정책 (USR5686E 공식 정석 준수):
   - 비표준 강제 하드코딩(DCB, MaximumPortSpeed)을 배제하고, Unimodem Properties의
     최대 DTE 속도(dwMaxDTERate = 115200 bps) 상한선 규격을 적용했습니다.
   - 기본 설치 시에는 최고 속도인 115,200 bps로 자동 설정되며,
     구형 PC(FIFO 버퍼가 없는 16450/8250 UART 장착 386/486 PC) 사용 시에는
     제어판 모뎀 등록정보에서 사용자가 속도를 57600, 38400, 19200 등으로
     자유롭게 낮춰 설정할 수 있습니다.

2. Zimodem 펌웨어 1:1 완벽 연동:
   - Zimodem 펌웨어 소스 전수 조사를 바탕으로 지원 명령어만 배타적으로 구성:
     • 초기화: ATZ (리셋), ATE0Q0V1 (에코 끔, 결과코드 켬, 상세 응답)
     • 흐름제어: AT&K3 (RTS/CTS), AT&K4 (XON/XOFF), AT&K0 (끔)
     • 스피커: ATM0 (음소거), ATM1 (다이얼 중 켬), ATM2 (항상 켬)
     • 발신: ATDT (톤 다이얼, 사운드 출력 연동), 01481 (윈도우 95 다이얼업 네트워킹 PPP 모드)
   - Zimodem에서 에러를 내는 타사 전용 명령어(&C1, &D2, &H1, \N3, %C1 등)는 일체 전송되지 않습니다.

[Windows 95 / 98 / ME / 2000 / XP 설치 및 재설치 방법]

※ 중요: 이전에 설치된 AirLink 56K 모뎀이 제어판에 등록되어 있다면,
  반드시 먼저 [제거]한 후 다시 설치해야 새 INF 설정이 반영됩니다.

1. 기존 모뎀 제거 (재설치 시 필수)
   - [시작] -> [설정] -> [제어판] -> [모뎀] 실행
   - 목록에서 기존 "AirLink 56K" 선택 후 [삭제] 클릭

2. 드라이버 파일 복사
   - Driver 폴더의 파일(AIRLINK.INF)을 플로피 디스크, 가상머신 공유 폴더,
     ISO 이미지 등을 통해 PC로 복사합니다.

3. 새 모뎀 수동 추가
   - [제어판] -> [모뎀] 실행 -> [추가] 버튼 클릭
   - "모뎀을 검색하지 않고 목록에서 직접 선택" 체크박스 체크 후 [다음] 클릭
   - [디스크 있음...] 버튼 클릭 -> AIRLINK.INF 가 위치한 폴더 지정 후 [확인] 클릭

4. 모델 및 포트 지정
   - 제조사: "Nexisson Tech Co., Ltd."
   - 모델: "AirLink 56K Serial Modem" 선택
   - AirLink가 연결된 통신 포트(예: 통신 포트 COM1) 선택 후 [다음] -> [마침]

5. 정상 동작 확인
   - [제어판] -> [모뎀] -> 모뎀 선택 후 [등록 정보] 클릭
     -> 정상적으로 포트, 최대 속도(115200), [연결] 탭 대화상자가 열리는지 확인
   - 새롬 데이타맨 98/Pro 등 통신 프로그램에서 모뎀 목록에 "AirLink 56K Serial Modem"이 정상 표시되는지 확인

==============================================================================
 (C) 2026 Nexisson Tech Co., Ltd. All rights reserved.
==============================================================================

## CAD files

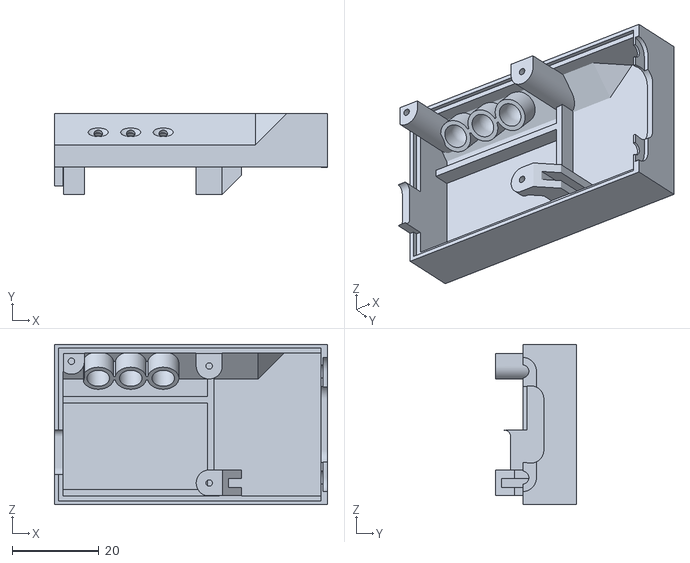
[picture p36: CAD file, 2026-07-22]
3d case/Case Front.stl
63.0 x 18.6 x 37.0

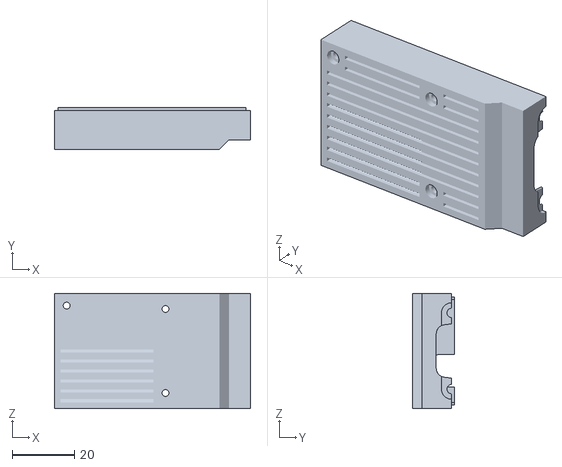
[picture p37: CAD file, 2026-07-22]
3d case/Case Back.stl
63.0 x 13.5 x 37.0

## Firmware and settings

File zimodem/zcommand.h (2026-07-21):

/*
   Copyright 2016-2026 Bo Zimmerman

   Licensed under the Apache License, Version 2.0 (the "License");
   you may not use this file except in compliance with the License.
   You may obtain a copy of the License at

           http://www.apache.org/licenses/LICENSE-2.0

   Unless required by applicable law or agreed to in writing, software
   distributed under the License is distributed on an "AS IS" BASIS,
   WITHOUT WARRANTIES OR CONDITIONS OF ANY KIND, either express or implied.
   See the License for the specific language governing permissions and
   limitations under the License.
*/

const int MAX_COMMAND_SIZE = 256;
static const char *CONFIG_FILE_OLD = "/zconfig.txt";
static const char *CONFIG_FILE = "/zconfig_v2.txt";
#define ZI_STATE_MACHINE_LEN 7
#define DEFAULT_TERMTYPE "Zimodem"
#define DEFAULT_BUSYMSG "\r\nBUSY\r\n7\r\n"

static void parseHostInfo(uint8_t *vbuf, char **hostIp, int *port,
                          char **username, char **password);
static bool validateHostInfo(uint8_t *vbuf);

enum ZResult {
  ZOK,
  ZERROR,
  ZCONNECT,
  ZNOCARRIER,
  ZNOANSWER,
  ZIGNORE,
  ZIGNORE_SPECIAL
};

enum ConfigOptions {
  CFG_WIFISSI = 0,
  CFG_WIFIPW = 1,
  CFG_BAUDRATE = 2,
  CFG_EOLN = 3,
  CFG_FLOWCONTROL = 4,
  CFG_ECHO = 5,
  CFG_RESP_SUPP = 6,
  CFG_RESP_NUM = 7,
  CFG_RESP_LONG = 8,
  CFG_PETSCIIMODE = 9,
  CFG_DCDMODE = 10,
  CFG_UART = 11,
  CFG_CTSMODE = 12,
  CFG_RTSMODE = 13,
  CFG_DCDPIN = 14,
  CFG_CTSPIN = 15,
  CFG_RTSPIN = 16,
  CFG_S0_RINGS = 17,
  CFG_S41_STREAM = 18,
  CFG_S60_LISTEN = 19,
  CFG_RIMODE = 20,
  CFG_DTRMODE = 21,
  CFG_DSRMODE = 22,
  CFG_RIPIN = 23,
  CFG_DTRPIN = 24,
  CFG_DSRPIN = 25,
  CFG_TIMEZONE = 26,
  CFG_TIMEFMT = 27,
  CFG_TIMEURL = 28,
  CFG_HOSTNAME = 29,
  CFG_PRINTDELAYMS = 30,
  CFG_PRINTSPEC = 31,
  CFG_TERMTYPE = 32,
  CFG_STATIC_IP = 33,
  CFG_STATIC_DNS = 34,
  CFG_STATIC_GW = 35,
  CFG_STATIC_SN = 36,
  CFG_BUSYMSG = 37,
  CFG_S62_TELNET = 38,
  CFG_S63_HANGUP = 39,
  CFG_ALTOPMODE = 40,
  CFG_LAST = 40
};

const ConfigOptions v2HexCfgs[] = {
    CFG_WIFISSI,   CFG_WIFIPW,  CFG_TIMEZONE, CFG_TIMEFMT,  CFG_TIMEURL,
    CFG_PRINTSPEC, CFG_BUSYMSG, CFG_HOSTNAME, CFG_TERMTYPE, (ConfigOptions)255};

enum BinType {
  BTYPE_NORMAL = 0,
  BTYPE_HEX = 1,
  BTYPE_DEC = 2,
  BTYPE_NORMAL_NOCHK = 3,
  BTYPE_NORMAL_PLUS = 4,
  BTYPE_HEX_PLUS = 5,
  BTYPE_DEC_PLUS = 6,
  BTYPE_INVALID = 7
};

enum OpModes { OPMODE_NONE, OPMODE_1650, OPMODE_1660, OPMODE_1670 };

class ZCommand : public ZMode {
  friend class WiFiClientNode;
  friend class ZConfig;
  friend class ZBrowser;
#if INCLUDE_IRCC
  friend class ZIRCMode;
#endif
#if INCLUDE_FTP
  friend class ZComet64Mode;
#endif

private:
  char CRLF[4];
  char LFCR[4];
  char LF[2];
  char CR[2];
  char BS = 8;

  ZSerial serial;

  WiFiClientNode *current = null;
  WiFiClientNode *nextConn = null;
  bool packetXOn = true;
  bool busyMode = false;
  char ringCounter = 1;
  BinType binType = BTYPE_NORMAL;
  uint8_t nbuf[MAX_COMMAND_SIZE];
  char hbuf[MAX_COMMAND_SIZE];
  int eon = 0;
  int lastServerClientId = 0;
  bool autoStreamMode = false;
  bool telnetSupport = false;
  bool preserveListeners = false;
  char *tempDelimiters = NULL;
  char *delimiters = NULL;
  char *tempMaskOuts = NULL;
  char *maskOuts = NULL;
  char *tempStateMachine = NULL;
  char *stateMachine = NULL;
  char *machineState = NULL;
  String machineQue = "";
  String previousCommand = "";
  int lastPacketId = -1;

  unsigned long lastPulseTimeMs = 0;
  int lastPulseState = DEFAULT_OTH_INACTIVE;
  unsigned int pulseWork = 0;
  String pulseBuf = "";

  byte CRC8(const byte *data, byte len);

  void showInitMessage();
  bool readSerialStream();
  bool checkPlusPlusPlusDisconnect();
  String getNextSerialCommand();
  ZResult doSerialCommand();
  void setConfigDefaults();
  void parseConfigOptions(String configArguments[]);
  void setOptionsFromSavedConfig(String configArguments[]);
  void setAltOpModeAdjustments();
  int pinStatusDecoder(int pinActive, int pinInactive);
  int getStatusRegister(const int snum, int crc8);
  ZResult setStatusRegister(const int snum, const int sval, int *crc8,
                            const ZResult oldRes);
  void packetOut(uint8_t id, uint8_t *cbuf, uint16_t bufLen, uint8_t num);
  void reSendLastPacket(WiFiClientNode *conn, uint8_t which);
  bool acceptNewConnection();
  void headerOut(const int channel, const int num, const int sz,
                 const int crc8);
  void sendConnectionNotice(int nodeId);
  void sendNextPacket();
  void connectionArgs(WiFiClientNode *c);
  void updateAutoAnswer();
  void checkPulseDial();
  uint8_t *doStateMachine(uint8_t *buf, uint16_t *bufLen, char **machineState,
                          String *machineQue, char *stateMachine);
  uint8_t *doMaskOuts(uint8_t *buf, uint16_t *bufLen, char *maskOuts);
  ZResult doWebDump(Stream *in, int len, const bool cacheFlag);
  ZResult doWebDump(const char *filename, const bool cache);

  ZResult doResetCommand(bool resetOpMode);
  ZResult doNoListenCommand(int vval, uint8_t *vbuf, int vlen, bool isNumber);
  ZResult doBaudCommand(int vval, uint8_t *vbuf, int vlen);
  ZResult doTransmitCommand(int vval, uint8_t *vbuf, int vlen, bool isNumber,
                            const char *dmodifiers, int *crc8);
  ZResult doLastPacket(int vval, uint8_t *vbuf, int vlen, bool isNumber);
  ZResult doConnectCommand(int vval, uint8_t *vbuf, int vlen, bool isNumber,
                           const char *dmodifiers);
  ZResult doWiFiCommand(int vval, uint8_t *vbuf, int vlen, bool isNumber,
                        const char *dmodifiers);
  ZResult doDialStreamCommand(unsigned long vval, uint8_t *vbuf, int vlen,
                              bool isNumber, const char *dmodifiers);
  ZResult doPhonebookCommand(unsigned long vval, uint8_t *vbuf, int vlen,
                             bool isNumber, const char *dmodifiers);
  ZResult doAnswerCommand(int vval, uint8_t *vbuf, int vlen, bool isNumber,
                          const char *dmodifiers);
  ZResult doHangupCommand(int vval, uint8_t *vbuf, int vlen, bool isNumber);
  ZResult doEOLNCommand(int vval, uint8_t *vbuf, int vlen, bool isNumber);
  ZResult doInfoCommand(int vval, uint8_t *vbuf, int vlen, bool isNumber);
  ZResult doWebStream(int vval, uint8_t *vbuf, int vlen, bool isNumber,
                      const char *filename, bool cache);
  ZResult doTimeZoneSetupCommand(int vval, uint8_t *vbuf, int vlen,
                                 bool isNumber);
#if INCLUDE_OTH_UPDATES
  ZResult doUpdateFirmware(int vval, uint8_t *vbuf, int vlen, bool isNumber);
#endif

public:
  int packetSize = 127;
  bool suppressResponses;
  bool numericResponses;
  bool longResponses;
  bool doEcho;
  int speakerMode = 1; // 0=끔, 1=다이얼중만(기본), 2=항상켬
  bool isKorean = true; // 언어 설정 (true: 한글, false: 영어)
  String EOLN;
  char EC = '+';
  char ECS[32];

  ZCommand();
  void loadConfig();
  bool reSaveConfig(int retries);

  FlowControlType getFlowControlType();
  int getConfigFlagBitmap();

  void sendOfficialResponse(ZResult res);
  void serialIncoming();
  void loop();
  void reset();
};

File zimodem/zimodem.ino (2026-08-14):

/*
   Copyright 2016-2026 Bo Zimmerman

   Licensed under the Apache License, Version 2.0 (the "License");
   you may not use this file except in compliance with the License.
   You may obtain a copy of the License at

     http://www.apache.org/licenses/LICENSE-2.0

   Unless required by applicable law or agreed to in writing, software
   distributed under the License is distributed on an "AS IS" BASIS,
   WITHOUT WARRANTIES OR CONDITIONS OF ANY KIND, either express or implied.
   See the License for the specific language governing permissions and
   limitations under the License.
*/
// #define TCP_SND_BUF                     4 * TCP_MSS
#define ZIMODEM_VERSION "1.16"
const char compile_date[] = __DATE__ " " __TIME__;
#define DEFAULT_NO_DELAY true
#define null 0

#define INCLUDE_IRCC true
#define INCLUDE_SD_SHELL true /* ESP32 only, requires SPI SD card interface */
// #define INCLUDE_CBMMODEM true  // ESP32 only, 1650, 1660, 1670, and Pulse
// Dialing support
#define INCLUDE_PING true
// #define INCLUDE_SSH true    // ESP32 only, adds SSH client
#define INCLUDE_HOSTCM true // requires sd shell
#define INCLUDE_FTP true
#define INCLUDE_COMET64 true // requires sd shell
// #define INCLUDE_OTH_UPDATES true // comment out if you make incompatible
// firmware
#define INCLUDE_SLIP true
#define INCLUDE_PPP true
#define SUPPORT_LED_PINS true // enable if you have the spare gpio pins and
// leds #define INCLUDE_CMDRX16 true // enable this if you are David or Kevin
// #define USE_DEVUPDATER true // only enable this if your name is Bo

// Figure out whether we are building for ESP8266 or ESP32
#if defined(ARDUINO_ESP32_DEV) || defined(ARDUINO_ARCH_ESP32)
#define ZIMODEM_ESP32
#elif defined(ARDUINO_ESP32S3_DEV) || defined(ARDUINO_ESP32C3_DEV)
#define ZIMODEM_ESP32
#elif defined(ESP32)
#define ZIMODEM_ESP32
#elif defined(ARDUINO_ESP320)
#define ZIMODEM_ESP32
#elif defined(ARDUINO_NANO32)
#define ZIMODEM_ESP32
#elif defined(ARDUINO_LoLin32)
#define ZIMODEM_ESP32
#elif defined(ARDUINO_ESPea32)
#define ZIMODEM_ESP32
#elif defined(ARDUINO_QUANTUM)
#define ZIMODEM_ESP32
#else
#define ZIMODEM_ESP8266
#undef INCLUDE_SSH
#undef INCLUDE_SD_SHELL
#undef INCLUDE_CBMMODEM
#endif

#if SUPPORT_LED_PINS
#ifdef GPIO_NUM_0
#define DEFAULT_PIN_AA GPIO_NUM_0
#define DEFAULT_PIN_RXTX GPIO_NUM_9
#define DEFAULT_PIN_WIFI GPIO_NUM_10
#else
#define DEFAULT_PIN_AA 0
#define DEFAULT_PIN_RXTX 9
#define DEFAULT_PIN_WIFI 10
#endif
#define DEFAULT_HS_BAUD 38400
#define DEFAULT_AA_ACTIVE HIGH
#define DEFAULT_AA_INACTIVE LOW
#define DEFAULT_RXTX_ACTIVE HIGH
#define DEFAULT_RXTX_INACTIVE LOW
#define DEFAULT_WIFI_ACTIVE HIGH
#define DEFAULT_WIFI_INACTIVE LOW
#endif

#define DEFAULT_BAUD_RATE 115200
#define DEFAULT_SERIAL_CONFIG SERIAL_8N1
#define RX_BUFFER_SIZE 4096
/*
 * Unused pins on WROOM32:
 * 2, 20, 21, 22.   36,39 (sensor)
 */

#ifdef ZIMODEM_ESP32
#define PIN_FACTORY_RESET GPIO_NUM_0
#define DEFAULT_FCT FCT_NORMAL
#if INCLUDE_CMDRX16 /* Configuration for the Commander X16 I/O Card */
#undef INCLUDE_SD_SHELL
#undef DEFAULT_FCT
#define DEFAULT_FCT FCT_NORMAL
#undef DEFAULT_BAUD_RATE
#define DEFAULT_BAUD_RATE 115200
#define DEFAULT_PIN_DCD GPIO_NUM_22
#define DEFAULT_PIN_CTS GPIO_NUM_19
#define DEFAULT_PIN_RTS GPIO_NUM_21
#define DEFAULT_PIN_RI GPIO_NUM_18
#define DEFAULT_PIN_DSR GPIO_NUM_23
#define DEFAULT_PIN_DTR GPIO_NUM_25
// #  define DEFAULT_PIN_OPA 26
#define DEFAULT_PIN_OPB GPIO_NUM_27
#define DEFAULT_PIN_OTH GPIO_NUM_26 // stream/command mode flag
#define DEFAULT_PIN_TXD GPIO_NUM_32
#define DEFAULT_PIN_RXD GPIO_NUM_33
#define DEFAULT_PIN_SND GPIO_NUM_4
#elif defined(                                                                 \
    ARDUINO_ESP32C3_DEV) /* Configuration for the Esp32C3 4MB Dev Board */
#undef INCLUDE_SD_SHELL
#undef PIN_FACTORY_RESET
#define DEFAULT_PIN_DCD GPIO_NUM_8
#define DEFAULT_PIN_CTS GPIO_NUM_3 // espdev rts pin
#define DEFAULT_PIN_RTS GPIO_NUM_2 // espdev cts pin
#define DEFAULT_PIN_RI GPIO_NUM_1
#define DEFAULT_PIN_DSR GPIO_NUM_4
#define DEFAULT_PIN_SND GPIO_NUM_6
#define DEFAULT_PIN_OTH GPIO_NUM_7 // pulse pin
#define DEFAULT_PIN_DTR GPIO_NUM_5
#elif defined(                                                                 \
    ARDUINO_ESP32S3_DEV) /* Configuration for the Esp32S3 16MB Dev Board */
#define DEFAULT_PIN_DCD GPIO_NUM_5
#define DEFAULT_PIN_CTS GPIO_NUM_18 // espdev rts pin
#define DEFAULT_PIN_RTS GPIO_NUM_17 // espdev cts pin
#define DEFAULT_PIN_RI GPIO_NUM_6
#define DEFAULT_PIN_DSR GPIO_NUM_1
#define DEFAULT_PIN_SND -1
#define DEFAULT_PIN_OTH -1 // pulse pin
#define DEFAULT_PIN_DTR GPIO_NUM_4
#define DEFAULT_PIN_TXD GPIO_NUM_16
#define DEFAULT_PIN_RXD GPIO_NUM_15
#define DEFAULT_PIN_SD_CS GPIO_NUM_14
#else /* Configuration for standard ESP32 4 & 8MB boards */
#define DEFAULT_PIN_DCD GPIO_NUM_14
#define DEFAULT_PIN_CTS GPIO_NUM_13
#define DEFAULT_PIN_RTS GPIO_NUM_15 // unused?
#define DEFAULT_PIN_RI GPIO_NUM_32
#define DEFAULT_PIN_DSR GPIO_NUM_12
#define DEFAULT_PIN_SND GPIO_NUM_25
#define DEFAULT_PIN_OTH GPIO_NUM_4 // pulse pin
#define DEFAULT_PIN_DTR GPIO_NUM_27
#endif
#define debugPrintf DBSerial.printf
#define SerialConfig uint32_t
#define UART_CONFIG_MASK 0x8000000
#define UART_NB_BIT_MASK 0B00001100 | UART_CONFIG_MASK
#define UART_NB_BIT_5 0B00000000 | UART_CONFIG_MASK
#define UART_NB_BIT_6 0B00000100 | UART_CONFIG_MASK
#define UART_NB_BIT_7 0B00001000 | UART_CONFIG_MASK
#define UART_NB_BIT_8 0B00001100 | UART_CONFIG_MASK
#define UART_PARITY_MASK 0B00000011
#define UART_PARITY_NONE 0B00000000
#define UART_NB_STOP_BIT_MASK 0B00110000
#define UART_NB_STOP_BIT_0 0B00000000
#define UART_NB_STOP_BIT_1 0B00010000
#define UART_NB_STOP_BIT_15 0B00100000
#define UART_NB_STOP_BIT_2 0B00110000
#define preEOLN(...)
// # define preEOLN serial.prints
#define echoEOLN(...) serial.prints(EOLN)
// # define echoEOLN serial.write
// # define HARD_DCD_HIGH 1
// # define HARD_DCD_LOW 1
#else // ESP-8266, e.g. ESP-01, ESP-12E
#define DEFAULT_PIN_DSR 13
#define DEFAULT_PIN_DTR 12
#define DEFAULT_PIN_RI 14
#define DEFAULT_PIN_RTS 4
#define DEFAULT_PIN_CTS 5 // is 0 for ESP-01
#define DEFAULT_PIN_DCD 2
#define DEFAULT_PIN_OTH -1 // pulse pin
#define DEFAULT_FCT FCT_NORMAL
#define debugPrintf doNothing // Serial.printf
#define preEOLN(...)
#define echoEOLN(...) serial.prints(EOLN)
#endif

#define DEFAULT_DCD_ACTIVE LOW
#define DEFAULT_DCD_INACTIVE HIGH
#define DEFAULT_CTS_ACTIVE LOW
#define DEFAULT_CTS_INACTIVE HIGH
#define DEFAULT_RTS_ACTIVE LOW
#define DEFAULT_RTS_INACTIVE HIGH
#define DEFAULT_RI_ACTIVE LOW
#define DEFAULT_RI_INACTIVE HIGH
#define DEFAULT_DSR_ACTIVE LOW
#define DEFAULT_DSR_INACTIVE HIGH
#define DEFAULT_DTR_ACTIVE LOW
#define DEFAULT_DTR_INACTIVE HIGH
#define DEFAULT_OTH_ACTIVE LOW
#define DEFAULT_OTH_INACTIVE HIGH

#define MAX_PIN_NO 50
#define INTERNAL_FLOW_CONTROL_DIV 380
#define DEFAULT_RECONNECT_DELAY 60000
#define MAX_RECONNECT_DELAY 1800000

class ZMode {
public:
  virtual void serialIncoming();
  virtual void loop();
};

#include "connSettings.h"
#include "filelog.h"
#include "pet2asc.h"
#include "phonebook.h"
#include "proto_ftp.h"
#include "proto_http.h"
#include "rt_clock.h"
#include "serout.h"
#include "stringstream.h"
#include "wificlientnode.h"
#include "wifiservernode.h"
#include "zcommand.h"
#include "zconfigmode.h"
#include "zimodem_sound.h"
#include "zprint.h"
#include "zstream.h"

#if INCLUDE_SD_SHELL
#if INCLUDE_HOSTCM
#include "zhostcmmode.h"
#endif
#if INCLUDE_FTP
#include "zcomet64mode.h"
#endif
#include "proto_kermit.h"
#include "proto_punter.h"
#include "proto_xmodem.h"
#include "proto_zmodem.h"
#include "zbrowser.h"

#endif
#if INCLUDE_SLIP
#include "zslipmode.h"
#endif
#if INCLUDE_PPP
#include "zpppmode.h"
#endif
#if INCLUDE_IRCC
#include "zircmode.h"
#endif

static WiFiClientNode *conns = null;
static WiFiServerNode *servs = null;
static PhoneBookEntry *phonebook = null;
static bool pinSupport[MAX_PIN_NO];
static int pinCache[MAX_PIN_NO];
static String termType = DEFAULT_TERMTYPE;
static String busyMsg = DEFAULT_BUSYMSG;
static bool debugUart = false;

static OpModes altOpMode = OPMODE_NONE;
static ZMode *currMode = null;
static ZStream streamMode;
static ZCommand commandMode;
static ZPrint printMode;
static ZConfig configMode;
static RealTimeClock zclock(0);
#if INCLUDE_SD_SHELL
#if INCLUDE_HOSTCM
static ZHostCMMode hostcmMode;
#endif
#if INCLUDE_FTP
static ZComet64Mode comet64Mode;
#endif
static ZBrowser browseMode;
#endif
#if INCLUDE_SLIP
static ZSLIPMode slipMode;
#endif
#if INCLUDE_PPP
static ZPPPMode pppMode;
#endif
#if INCLUDE_IRCC
static ZIRCMode ircMode;
#endif

enum BaudState {
  BS_NORMAL,
  BS_SWITCH_TEMP_NEXT,
  BS_SWITCHED_TEMP,
  BS_SWITCH_NORMAL_NEXT
};

static String wifiSSI;
static String wifiPW;
static String hostname = "AirLink-56K";
static IPAddress *staticIP = null;
static IPAddress *staticDNS = null;
static IPAddress *staticGW = null;
static IPAddress *staticSN = null;
static unsigned long lastConnectAttempt = 0;
static unsigned long nextReconnectDelay =
    0; // zero means don't attempt reconnects
static SerialConfig serialConfig = DEFAULT_SERIAL_CONFIG;
static int baudRate = DEFAULT_BAUD_RATE;
int qosBps = 0; // 0 = unlimited, otherwise speed in bps (e.g. 56000)
float qosTokens = 3000.0; // Token bucket limit for authentic modem speeds
unsigned long qosLastTime = 0;
static int dequeSize = 1 + (DEFAULT_BAUD_RATE / INTERNAL_FLOW_CONTROL_DIV);
static BaudState baudState = BS_NORMAL;
static unsigned long resetPushTimer = 0;
static int tempBaud = -1; // -1 do nothing
static unsigned int plussesInARow = 0;
static unsigned long lastInputTimeMs = 0;
static int dcdStatus = DEFAULT_DCD_INACTIVE;
static int pinDCD = DEFAULT_PIN_DCD;
static int pinCTS = DEFAULT_PIN_CTS;
static int pinRTS = DEFAULT_PIN_RTS;
static int pinDSR = DEFAULT_PIN_DSR;
static int pinDTR = DEFAULT_PIN_DTR;
static int pinOTH = DEFAULT_PIN_OTH;
static int pinRI = DEFAULT_PIN_RI;
static int dcdActive = DEFAULT_DCD_ACTIVE;
static int dcdInactive = DEFAULT_DCD_INACTIVE;
static int ctsActive = DEFAULT_CTS_ACTIVE;
static int ctsInactive = DEFAULT_CTS_INACTIVE;
static int rtsActive = DEFAULT_RTS_ACTIVE;
static int rtsInactive = DEFAULT_RTS_INACTIVE;
static int riActive = DEFAULT_RI_ACTIVE;
static int riInactive = DEFAULT_RI_INACTIVE;
static int dtrActive = DEFAULT_DTR_ACTIVE;
static int dtrInactive = DEFAULT_DTR_INACTIVE;
static int dsrActive = DEFAULT_DSR_ACTIVE;
static int dsrInactive = DEFAULT_DSR_INACTIVE;
static int othActive = DEFAULT_OTH_ACTIVE;
static int othInactive = DEFAULT_OTH_INACTIVE;

static int getDefaultCtsPin() { return DEFAULT_PIN_CTS; }

static void doNothing(const char *format, ...) {}

static void s_pinWrite(uint8_t pinNo, uint8_t value) {
  if (pinNo < MAX_PIN_NO && pinSupport[pinNo]) {
    pinCache[pinNo] = value;
    digitalWrite(pinNo, value);
  }
}

static void setHostName(const char *hname) {
#ifdef ZIMODEM_ESP32
#ifdef TCPIP_ADAPTER_IF_STA
  tcpip_adapter_set_hostname(TCPIP_ADAPTER_IF_STA, hname);
#else
  WiFi.setHostname(hname);
#endif
#else
  WiFi.hostname(hname);
#endif
}

static void setNewStaticIPs(IPAddress *ip, IPAddress *dns, IPAddress *gateWay,
                            IPAddress *subNet) {
  if (staticIP != null)
    delete staticIP;
  staticIP = ip;
  if (staticDNS != null)
    delete staticDNS;
  staticDNS = dns;
  if (staticGW != null)
    delete staticGW;
  staticGW = gateWay;
  if (staticSN != null)
    delete staticSN;
  staticSN = subNet;
}

static bool connectWifi(const char *ssid, const char *password, IPAddress *ip,
                        IPAddress *dns, IPAddress *gateWay, IPAddress *subNet) {
  while (WiFi.status() == WL_CONNECTED) {
    WiFi.disconnect();
    delay(100);
    yield();
  }
#ifndef ZIMODEM_ESP32
  if (hostname.length() > 0)
    setHostName(hostname.c_str());
#endif
  WiFi.mode(WIFI_STA);
  if ((ip != null) && (gateWay != null) && (dns != null) && (subNet != null)) {
    if (!WiFi.config(*ip, *gateWay, *subNet, *dns))
      return false;
  }
  WiFi.begin(ssid, password);
#if defined(ARDUINO_MAKERGO_C3_SUPERMINI) ||                                   \
    defined(ARDUINO_NOLOGO_ESP32C3_SUPER_MINI)
  WiFi.setTxPower(WIFI_POWER_8_5dBm);
#endif
  if (hostname.length() > 0)
    setHostName(hostname.c_str());
  bool amConnected =
      (WiFi.status() == WL_CONNECTED) &&
      (strcmp(WiFi.localIP().toString().c_str(), "0.0.0.0") != 0);
  int WiFiCounter = 0;
  while ((!amConnected) && (WiFiCounter < 20)) {
    WiFiCounter++;
    if (!amConnected)
      delay(500);
    amConnected = (WiFi.status() == WL_CONNECTED) &&
                  (strcmp(WiFi.localIP().toString().c_str(), "0.0.0.0") != 0);
  }
  lastConnectAttempt = millis();
  if (lastConnectAttempt ==
      0) // it IS possible for millis() to be 0, but we need to ignore it.
    lastConnectAttempt = 1; // 0 is a special case, so skip it

  if (!amConnected) {
    nextReconnectDelay = 0; // assume no retry is desired.. let the caller set
                            // it up, as it could be bad PW
    WiFi.disconnect();
  } else
    nextReconnectDelay =
        DEFAULT_RECONNECT_DELAY; // if connected, we always want to try reconns
                                 // in the future


  if (WiFi.status() == WL_CONNECTED)
    debugPrintf("Connected to %s with IP %s.\r\n", ssid,
                WiFi.localIP().toString().c_str());
  return (WiFi.status() == WL_CONNECTED);
}

static void checkBaudChange() {
  switch (baudState) {
  case BS_SWITCH_TEMP_NEXT:
    changeBaudRate(tempBaud);
    baudState = BS_SWITCHED_TEMP;
    break;
  case BS_SWITCH_NORMAL_NEXT:
    changeBaudRate(baudRate);
    baudState = BS_NORMAL;
    break;
  default:
    break;
  }
}

static void changeBaudRate(int baudRate) {
  flushSerial(); // blocking, but very very necessary
  delay(500);    // give the client half a sec to catch up
  logPrintfln("Baud change to %d.", baudRate);
  dequeSize = 1 + (baudRate / INTERNAL_FLOW_CONTROL_DIV);
  debugPrintf("Baud %d, Deque constant now: %d\r\n", baudRate, dequeSize);
#ifdef ZIMODEM_ESP32
  HWSerial.updateBaudRate(baudRate);
#else
  HWSerial.begin(baudRate, serialConfig); // Change baud rate
#endif

}

static void changeSerialConfig(SerialConfig conf) {
  flushSerial(); // blocking, but very very necessary
  delay(500);    // give the client half a sec to catch up
  debugPrintf("Config changing to %dbps, %d.\r\n", baudRate, (int)conf);
  dequeSize = 1 + (baudRate / INTERNAL_FLOW_CONTROL_DIV);
  debugPrintf("Deque constant now: %d\r\n", dequeSize);
#ifdef DEFAULT_PIN_RXD
  debugPrintf("Using BPS %d, RXD %d, TXD %d\r\n", baudRate, DEFAULT_PIN_RXD,
              DEFAULT_PIN_TXD);
  HWSerial.begin(baudRate, conf, DEFAULT_PIN_RXD, DEFAULT_PIN_TXD);
#else
  HWSerial.begin(baudRate, conf); // Change baud rate
#endif
  debugPrintf("Config changed.\r\n");
}

static int checkOpenConnections() {
  int num = WiFiClientNode::getNumOpenWiFiConnections();
  if (num == 0) {
    if ((dcdStatus == dcdActive) && (dcdStatus != dcdInactive)) {
      dcdStatus = dcdInactive;
      s_pinWrite(pinDCD, dcdStatus);
      if (baudState == BS_SWITCHED_TEMP)
        baudState = BS_SWITCH_NORMAL_NEXT;
      if (currMode == &commandMode)
        clearSerialOutBuffer();
    }
  } else {
    if ((dcdStatus == dcdInactive) && (dcdStatus != dcdActive)) {
      dcdStatus = dcdActive;
      s_pinWrite(pinDCD, dcdStatus);
      if ((tempBaud > 0) && (baudState == BS_NORMAL))
        baudState = BS_SWITCH_TEMP_NEXT;
    }
  }
  return num;
}

static int processPlusPlusPlus(uint8_t c) {
  if (c < 0)
    return 0;
  int plusOut = 0;
  if (c == commandMode.EC) {
    bool timeout = (millis() - lastInputTimeMs) > 900;
    if (plussesInARow == 0) {
      if (timeout)
        plussesInARow = 1; // it begins!
      // else got a +, but too quick after last char, so keep at 0
    } else if (!timeout) // quick PLUS
    {
      if (plussesInARow < 3)
        plussesInARow++;
      else {
        plusOut = plussesInARow; // sur-plus, so reject
        plussesInARow = 0;       // spamming plusses clears!
      }
    } else // plus long after timeout
    {
      plusOut = plussesInARow;
      plussesInARow = 1;
    }
  } else if (plussesInARow > 0) {
    plusOut = plussesInARow;
    plussesInARow = 0;
  }
  lastInputTimeMs = millis();
  return plusOut;
}

static bool checkPlusPlusPlusEscape() {
  if ((plussesInARow == 3) && ((millis() - lastInputTimeMs) > 900)) {
    plussesInARow = 0;
    return true;
  }
  return false;
}

void setup() {
  for (int i = 0; i < MAX_PIN_NO; i++)
    pinSupport[i] = false;
#ifdef ZIMODEM_ESP32
  DBSerial.begin(115200); // the debug port
  DBSerial.setDebugOutput(true);
#ifdef ARDUINO_ESP32S3_DEV
  pinSupport[1] = true;
  for (int i = 5; i <= 17; i++)
    pinSupport[i] = true;
  for (int i = 19; i <= 21; i++)
    pinSupport[i] = true;
  for (int i = 36; i <= 38; i++)
    pinSupport[i] = true;
  pinSupport[47] = true;
  pinSupport[48] = true;
#elif defined(ARDUINO_ESP32C3_DEV)
  for (int i = 0; i <= 21; i++) {
    if (i >= 11 && i <= 17) continue; // Skip flash pins usually
    pinSupport[i] = true;
  }
#else
  pinSupport[2] = true;
  pinSupport[4] = true;
  pinSupport[5] = true;
  for (int i = 12; i <= 23; i++)
    pinSupport[i] = true;
  for (int i = 25; i <= 27; i++)
    pinSupport[i] = true;
  for (int i = 32; i <= 36; i++)
    pinSupport[i] = true;
  pinSupport[39] = true;
#endif
#else
  pinSupport[0] = true;
  pinSupport[2] = true;
  if ((ESP.getFlashChipRealSize() / 1024) >=
      4096) // assume this is a strykelink/esp12e
  {
    pinSupport[4] = true;
    pinSupport[5] = true;
    for (int i = 9; i <= 16; i++)
      pinSupport[i] = true;
    pinSupport[11] = false;
  }
#endif
#ifdef DEFAULT_PIN_OPB
  static bool OPB_stat = 0;
  pinMode(DEFAULT_PIN_OPB, INPUT);
  OPB_stat = digitalRead(DEFAULT_PIN_OPB);
#endif

  debugPrintf("Zimodem %s firmware starting initialization\r\n",
              ZIMODEM_VERSION);
  initSDShell();
  currMode = &commandMode;
  if (!SPIFFS.begin()) {
    SPIFFS.format();
    SPIFFS.begin();
    debugPrintf("SPIFFS Formatted.\r\n");
  }
#ifdef DEFAULT_PIN_RXD
  debugPrintf("Using BPS %d, RXD %d, TXD %d\r\n", DEFAULT_BAUD_RATE,
              DEFAULT_PIN_RXD, DEFAULT_PIN_TXD);
  HWSerial.begin(DEFAULT_BAUD_RATE, DEFAULT_SERIAL_CONFIG, DEFAULT_PIN_RXD,
                 DEFAULT_PIN_TXD);
#else
  HWSerial.begin(DEFAULT_BAUD_RATE, DEFAULT_SERIAL_CONFIG); // Start Serial
#endif
  HWSerial.setRxBufferSize(RX_BUFFER_SIZE);
  commandMode.loadConfig();
  snd_init(); // 사운드 엔진 초기화 (타이머 ISR 시작)
  PhoneBookEntry::loadPhonebook();
  dcdStatus = dcdInactive;
  s_pinWrite(pinDCD, dcdStatus);
  flushSerial();
#if SUPPORT_LED_PINS
  s_pinWrite(DEFAULT_PIN_WIFI, DEFAULT_WIFI_INACTIVE);
  s_pinWrite(DEFAULT_PIN_RXTX, DEFAULT_RXTX_INACTIVE);
#endif
}

void checkReconnect() {
  if ((WiFi.status() != WL_CONNECTED) && (nextReconnectDelay > 0) &&
      (lastConnectAttempt > 0) && (wifiSSI.length() > 0)) {
    unsigned long now = millis();
    if (lastConnectAttempt > now)
      lastConnectAttempt = 1;
    if (now > lastConnectAttempt + nextReconnectDelay) {
      debugPrintf("Attempting Reconnect to %s\r\n", wifiSSI.c_str());
      unsigned long oldReconnectDelay = nextReconnectDelay;
      if (!connectWifi(wifiSSI.c_str(), wifiPW.c_str(), staticIP, staticDNS,
                       staticGW, staticSN))
        debugPrintf("Unable to reconnect to %s.\r\n", wifiSSI.c_str());
      nextReconnectDelay = oldReconnectDelay * 2;
      if (nextReconnectDelay > MAX_RECONNECT_DELAY)
        nextReconnectDelay = DEFAULT_RECONNECT_DELAY;
    }
  }
}
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
void loop() {
  checkFactoryReset();
  checkReconnect();
#if SUPPORT_LED_PINS
  if (WiFi.status() == WL_CONNECTED) {
    s_pinWrite(DEFAULT_PIN_WIFI, DEFAULT_WIFI_ACTIVE);
  } else if (wifiSSI.length() > 0) {
    s_pinWrite(DEFAULT_PIN_WIFI, ((millis() % 1000) < 500) ? DEFAULT_WIFI_ACTIVE : DEFAULT_WIFI_INACTIVE);
  } else {
    s_pinWrite(DEFAULT_PIN_WIFI, DEFAULT_WIFI_INACTIVE);
  }
  if ((millis() - lastRxtxTime < 500) || (snd_state != SND_IDLE && snd_state != SND_DONE)) {
    s_pinWrite(DEFAULT_PIN_RXTX, DEFAULT_RXTX_ACTIVE);
  } else {
    s_pinWrite(DEFAULT_PIN_RXTX, DEFAULT_RXTX_INACTIVE);
  }
#endif

  // USB 시리얼(DBSerial)을 통한 비상 명령어 처리
  if (DBSerial.available()) {
    String line = DBSerial.readStringUntil('\n');
    line.trim();
    if (line.equalsIgnoreCase("HELP")) {
      DBSerial.println("=== USB 비상 콘솔 명령어 ===");
      DBSerial.println(" BAUD=<rate>  : 메인 시리얼 속도 변경 및 저장 (예: BAUD=115200)");
      DBSerial.println(" RESET        : 재부팅");
      DBSerial.println(" FACTORY      : 공장 초기화 (모든 설정 초기화)");
      DBSerial.println("============================");
    } else if (line.startsWith("BAUD=")) {
      int newBaud = line.substring(5).toInt();
      if (newBaud > 0) {
        baudRate = newBaud;
        changeBaudRate(baudRate);
        commandMode.reSaveConfig(10);
        DBSerial.printf("Baud rate changed to %d and saved.\n", baudRate);
      }
    } else if (line.equalsIgnoreCase("RESET")) {
      DBSerial.println("Rebooting...");
      ESP.restart();
    } else if (line.equalsIgnoreCase("FACTORY")) {
      DBSerial.println("Factory Reset...");
      SPIFFS.remove(CONFIG_FILE);
      ESP.restart();
    }
  }

  if (HWSerial.available()) {
    lastRxtxTime = millis();
    currMode->serialIncoming();
  }
  currMode->loop();
  zclock.tick();
}

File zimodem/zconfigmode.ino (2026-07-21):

/*
   Copyright 2016-2026 Bo Zimmerman

   Licensed under the Apache License, Version 2.0 (the "License");
   you may not use this file except in compliance with the License.
   You may obtain a copy of the License at

     http://www.apache.org/licenses/LICENSE-2.0

   Unless required by applicable law or agreed to in writing, software
   distributed under the License is distributed on an "AS IS" BASIS,
   WITHOUT WARRANTIES OR CONDITIONS OF ANY KIND, either express or implied.
   See the License for the specific language governing permissions and
   limitations under the License.
*/

void ZConfig::switchTo() {
  debugPrintf("\r\nMode:Config\r\n");
  currMode = &configMode;
  serial.setFlowControlType(commandMode.serial.getFlowControlType());
  serial.setPetsciiMode(commandMode.serial.isPetsciiMode());
  savedEcho = commandMode.doEcho;
  newListen = commandMode.preserveListeners;
  commandMode.doEcho = true;
  serverSpec.port = 6502;
  serverSpec.flagsBitmap = commandMode.getConfigFlagBitmap() & (~FLAG_ECHO);
  if (servs)
    serverSpec = *servs;
  serial.setXON(true);
  showMenu = true;
  EOLN = commandMode.EOLN;
  EOLNC = EOLN.c_str();
  currState = ZCFGMENU_MAIN;
  lastNumber = 0;
  lastAddress = "";
  lastOptions = "";
  settingsChanged = false;
  lastNumNetworks = 0;
  lastIP = (staticIP != null) ? *staticIP : WiFi.localIP();
  lastDNS = (staticDNS != null) ? *staticDNS : IPAddress(192, 168, 0, 1);
  lastGW = (staticGW != null) ? *staticGW : IPAddress(192, 168, 0, 1);
  lastSN = (staticSN != null) ? *staticSN : IPAddress(255, 255, 255, 0);
}

void ZConfig::serialIncoming() {
  bool crReceived = commandMode.readSerialStream();
  if (crReceived) {
    doModeCommand();
  }
}

void ZConfig::switchBackToCommandMode() {
  debugPrintf("\r\nMode:Command\r\n");
  commandMode.doEcho = savedEcho;
  currMode = &commandMode;
}
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

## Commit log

2026-07-14 Edit
    Modifications:
    - Added AirLink Brand (Based on ESP32-C3 + Buzzer + MAX3232)
    - Disabled incompatible features and unnecessary commands exclusively for ESP32-C3
    - Modified from retro PC to IBM PC exclusive
    - Added Modem Sound Emulation (Added telephone ringing, DTMF dial tone, modem connection sounds (V.90) and linked them. The actual input address is replaced with DTMF for sound output.)
    - Revamped VT100 based interactive configuration menu (AT+CONFIG)
    - Added Korean (EUC-KR) support (Added English/Korean settings)
    - Added Help function (AT+HELP)
    - Added minor convenience features
    - Supported the latest Arduino IDE and ESP-IDF v5.0 or higher
    [zcommand.h, zcommand.ino, zconfigmode.h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]
2026-07-21 1.14 update
    ## 🚀 주요 업데이트 내용 (Major Updates)
    ### 1. Windows 95 호환성: PPP 인증(PAP) 기능 최초 구현 및 IPCP 교섭 로직 개선
    * **PAP 인증 프로토콜 신규 구현 (`zpppmode.ino`)**:
    * 기존 Zimodem 펌웨어에는 아예 존재하지 않았던 PAP(Password Authentication Protocol) 인증 응답 로직을 바닥부터 새로 구현.
    * 이로 인해 Windows 95에서 PPP 다이얼업 접속 시 "사용자 이름 및 암호 확인 중..." (연결 중) 단계에서 무한정 멈추어 아예 넘어가지 못하던 치명적인 호환성 문제 완벽 해결.
    * **IPCP Conf-Req 상태 관리 및 분리**:
    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
2026-07-21 1.15 update
    변경 사항 요약 (Changes Made)
    🔊 1. FreeRTOS 사운드 태스크 무한 대기 수정
    zimodem_sound.h
    snd_task_fn() 내 while (snd_state == SND_WAIT_RESULT) 대기 루프에 30초 타임아웃을 추가하였습니다.
    다이얼링 도중 네트워크 오류나 예외로 인해 snd_finish()가 호출되지 않는 상황에서도 30초 후 태스크가 스스로 정리되어 종료(SND_DONE)되며, snd_task_handle을 NULL로 안전하게 해제하여 모뎀 사운드가 영구히 먹통이 되는 현상을 방지하였습니다.
    💣 2. C++ 메모리 동적 할당/해제 불일치 교정 (Mismatched Deallocations)
    zcommand.ino
    new uint8_t[]로 할당된 동적 배열 vbuf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
    [connSettings.ino, pet2asc.ino, zcommand.ino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]
2026-07-22 Reference Design Added
    [Case Back.stl, Case Front.stl]
2026-08-14 1.16 Update
    Zimodem-AirLink v1.16 수정사항:
    1. 시리얼 송신 버퍼 8배 확장
    기존 4KB 시리얼 버퍼 → 32KB로 확장 (대용량 웹/이미지 다운로드 시 패킷 유실 방지)
    2. PPP 프레임 버퍼 크기 계산 최적화
    불필요하게 2배 이상 뻥튀기되던 패킷 크기 계산식 수정 → 버퍼 공간 효율 100% 활용
    3. PPP 수신 버퍼 힙 메모리 안전장치 추가
    깨진 패킷 유입 시 메모리를 계속 늘리던 문제 수정 → 최대 4KB 고정 및 즉시 폐기 (메모리 누수 및 다운 방지)
    4. DTR 신호 감지 안정화
    DTR 핀이 없는 배선(3선/5선) 환경에서 플로팅 노이즈로 인해 연결이 끊기던 문제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
    [zimodem.ino, zpppmode.h, zpppmode.ino]
2026-08-20 Driver Test
2026-09-22 edit(테스트안했음)
2026-09-23 edit(실테스트안함)
